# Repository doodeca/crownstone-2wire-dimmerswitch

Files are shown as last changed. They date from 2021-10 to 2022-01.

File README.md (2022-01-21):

# Crownstone 2-Wire Dimmer/switch
A repository to document the design process of the Crownstone 2-wire dimmer/switch prototype.

## Schematics 
| Version | Changes | 
|---|---|
| [V1](https://github.com/doodeca/crownstone-2wire-dimmerswitch/raw/main/hardware/schematics/Schematic_V1.pdf) | First draft |
| [V1.1](https://github.com/doodeca/crownstone-2wire-dimmerswitch/raw/main/hardware/schematics/Schematic_V1.1.pdf) | Replace LDO with a DC/DC converter, replace LNK3302 by LNK302, add opamp for ZCD |
| [V1.2](https://github.com/doodeca/crownstone-2wire-dimmerswitch/raw/main/hardware/schematics/Schematic_V1.2.pdf) | Change value of R5 to 82k |
| [V1.3](https://github.com/doodeca/crownstone-2wire-dimmerswitch/raw/main/hardware/schematics/Schematic_V1.3.pdf) | Add rotary encoder |
| [V1.4](https://github.com/doodeca/crownstone-2wire-dimmerswitch/raw/main/hardware/schematics/Schematic_V1.4.pdf) | Add dimmer circuit, change rotary encoder |

## Simulations
[230V AC - 15V DC buck converter using LinkSwitch, half rectifier](https://github.com/doodeca/crownstone-2wire-dimmerswitch/blob/main/hardware/simulations/Pspice/README.md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)\
[230V AC - 15V DC buck converter using LinkSwitch, full rectifier](https://github.com/doodeca/crownstone-2wire-dimmerswitch/blob/main/hardware/simulations/Pspice/README.md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)\
[3.3V buck converter using LT1934](https://github.com/doodeca/crownstone-2wire-dimmerswitch/blob/main/hardware/simulations/LTspice/README.md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)\
[Zero Cross Detection using an opamp](https://github.com/doodeca/crownstone-2wire-dimmerswitch/blob/main/hardware/simulations/LTspice/README.md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)

## Tests
[15V DC buck converter using LinkSwitch](https://github.com/doodeca/crownstone-2wire-dimmerswitch/blob/main/hardware/tests/README.md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)\
[3.3V buck converter using LT1934](https://github.com/doodeca/crownstone-2wire-dimmerswitch/blob/main/hardware/tests/README.md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)\
[Zero Cross Detection using an opamp](https://github.com/doodeca/crownstone-2wire-dimmerswitch/blob/main/hardware/tests/README.md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)

## Documents
[Report](https://docs.google.com/viewer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)

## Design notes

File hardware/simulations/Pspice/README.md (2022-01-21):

# LNK302 buck converter half rectifier

LinkSwitch-TN series DC/DC converter ICs combine a on/off controller and an integrated switch. LNK302 is used in a buck topology with direct feedback [datasheet](https://ac-dc.power.com/sites/default/files/product-docs/an37.pdf).
PI Expert's [spreadsheet](https://github.com/doodeca/crownstone-2wire-dimmerswitch/raw/main/hardware/simulations/Pspice/LinkSwitch-TN_buck_PIExpert%20.pdf) tool is used to calculate the external component values. 

## Simulation specific components description 

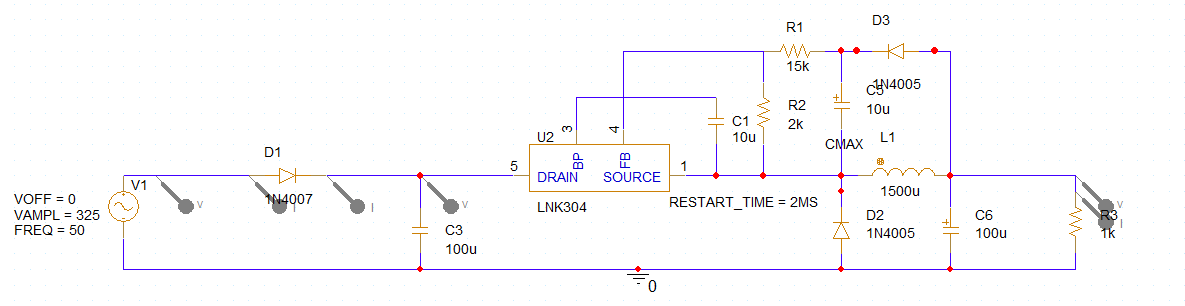
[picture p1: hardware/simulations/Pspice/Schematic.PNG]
Schematic


V1 simulates a 230Vrms source at 50 hertz, R3 simulates the load.

## Simulation results

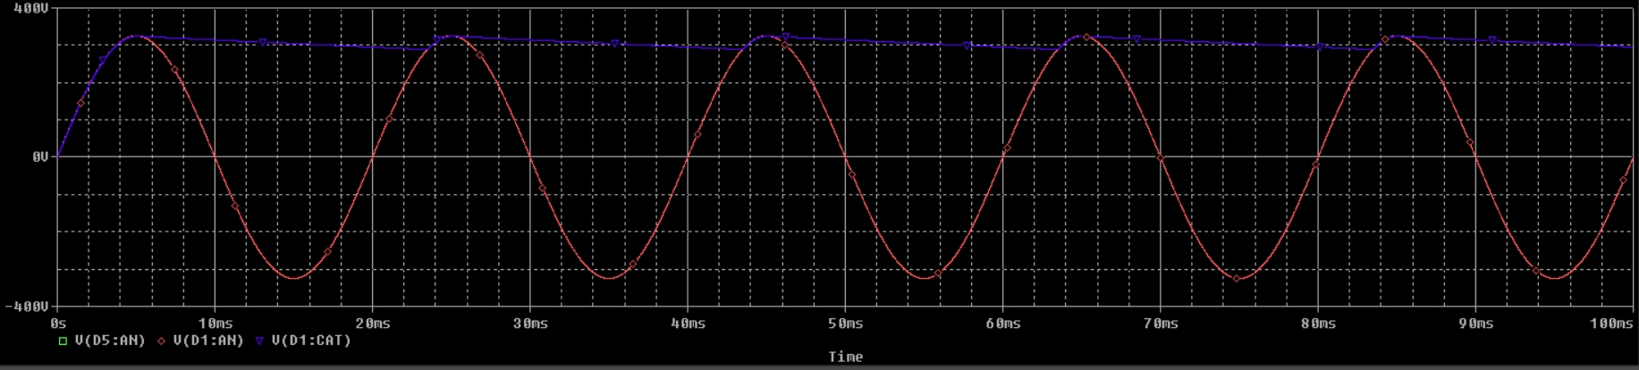
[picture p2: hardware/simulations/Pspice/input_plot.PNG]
Plot_in


This plot shows the input signal (red) and the rectified input (blue).

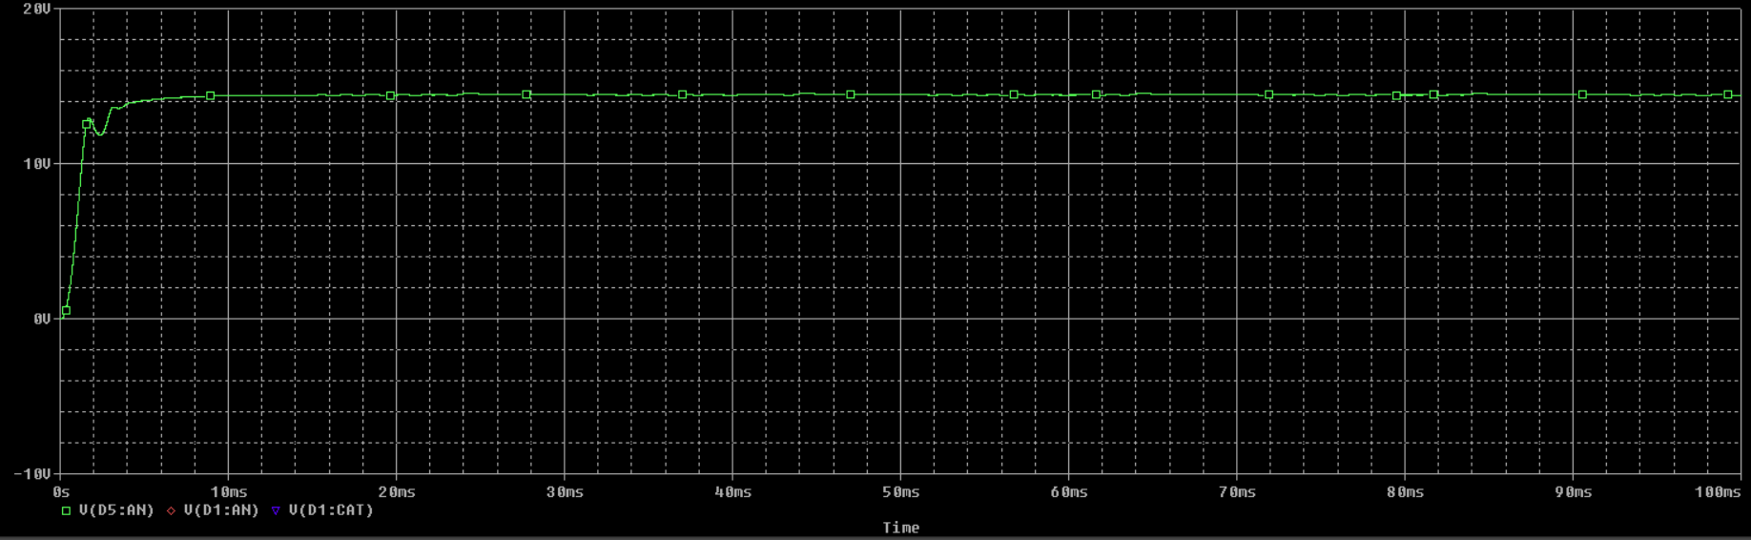
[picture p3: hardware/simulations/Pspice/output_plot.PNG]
Plot_out


In this plot the output voltage is shown.

# LNK302 buck converter full rectifier

## Simulation specific components description 

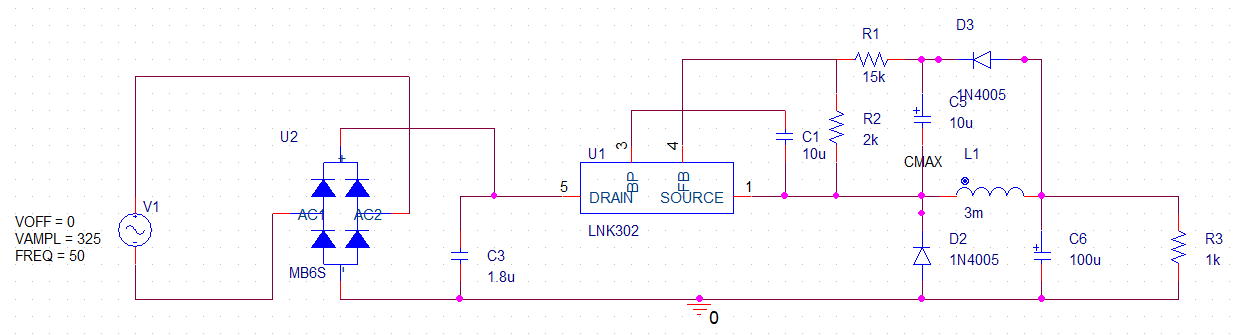
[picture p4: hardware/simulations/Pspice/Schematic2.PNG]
Schematic


V1 simulates a 230Vrms source at 50 hertz, R3 simulates the load.

## Simulation results

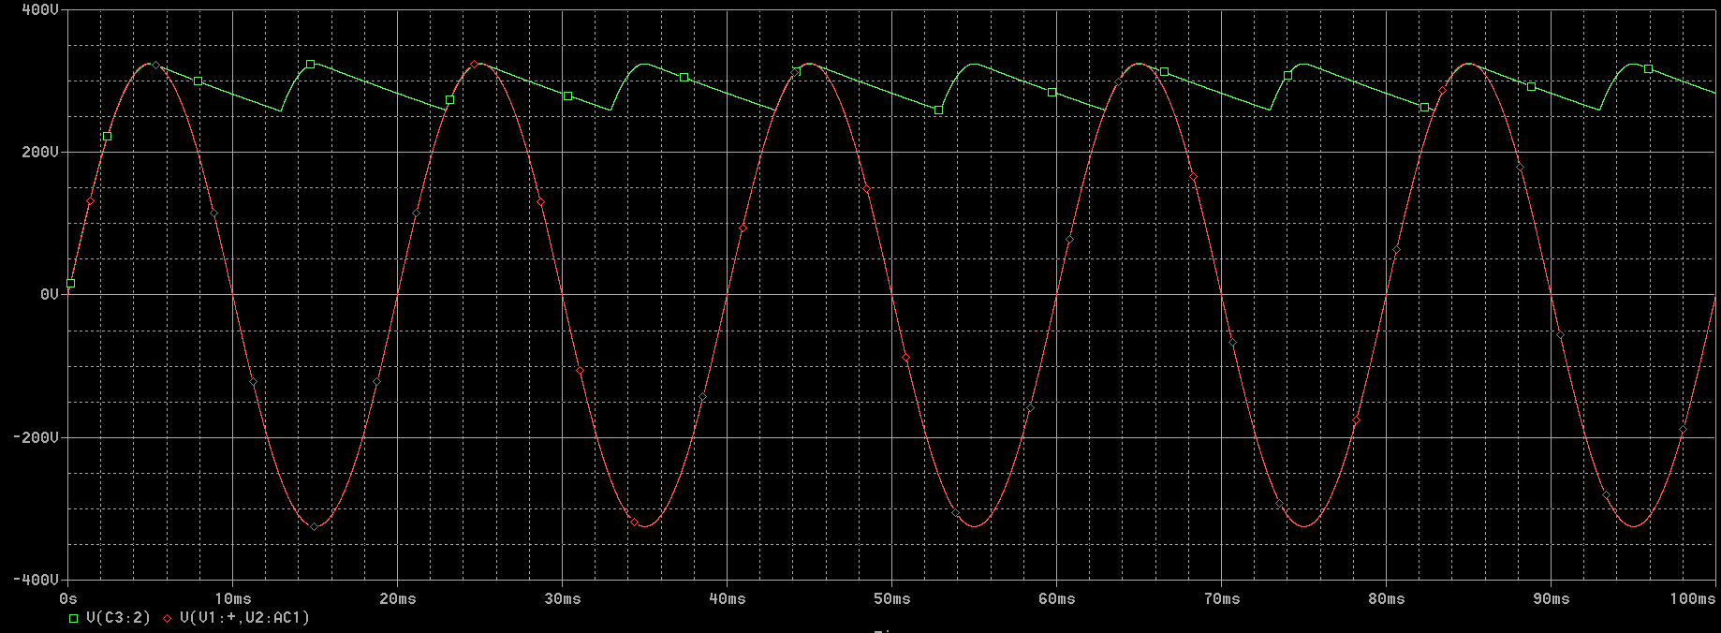
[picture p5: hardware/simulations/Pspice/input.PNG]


This plot shows the input signal (red) and the full rectified input (green).

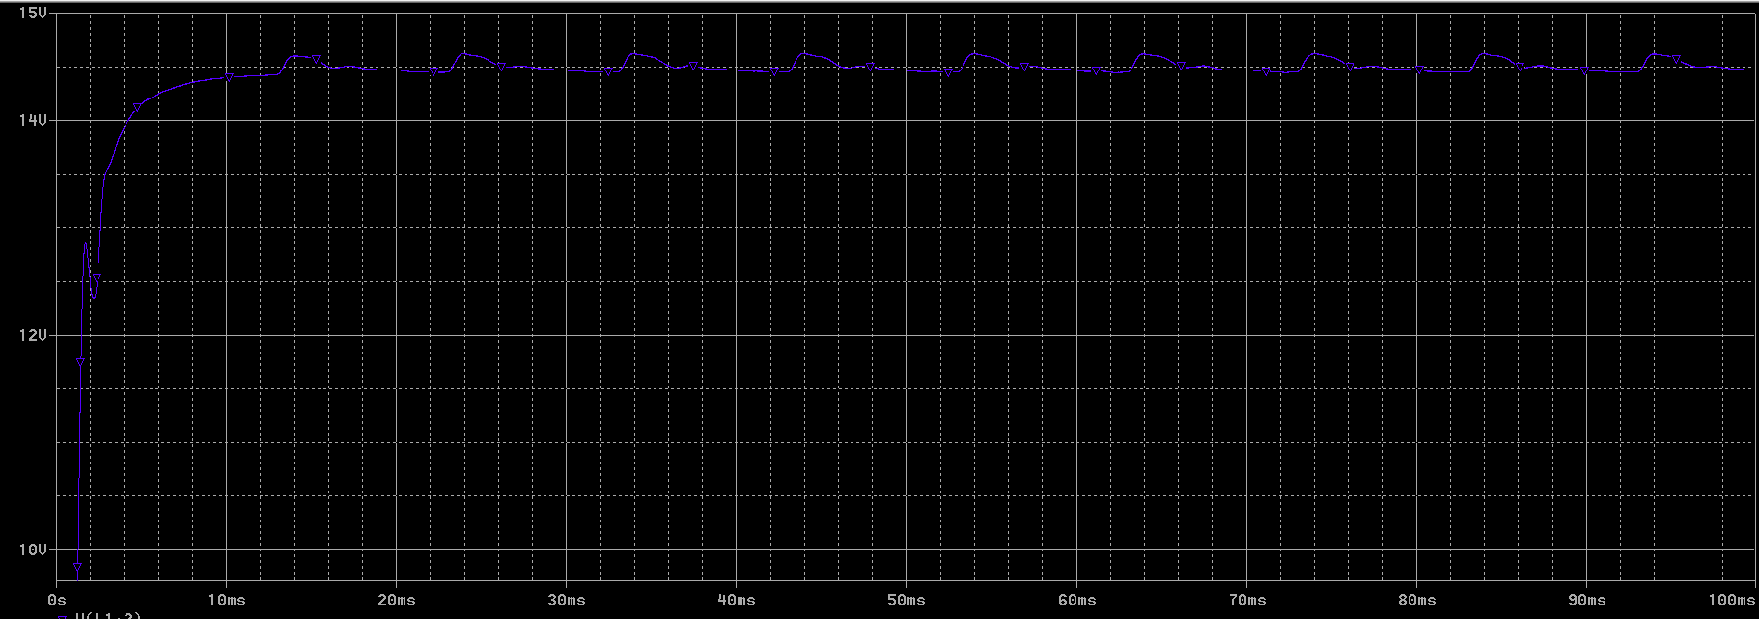
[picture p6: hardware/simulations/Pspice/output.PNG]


In this plot the output voltage is shown.

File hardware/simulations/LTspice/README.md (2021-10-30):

# LT1934-1 buck converter

LT1934-1 is a step-down DC/DC converter IC with an integrated switch, able to supply up to 60mA of output current. [datasheet](https://www.analog.com/media/en/technical-documentation/data-sheets/1934fe.pdf).

## Simulation specific components description 

The purpose of R4 and R5 is to be able to measure the current from the source and the current going into the switching regulator.\
V1 simulates a 15V DC source with a 0.15V sine ripple at 62kHz. B1 simulates a 15V DC source with noise +-0.5V.\
R3 simulates the load.

## Simulation results

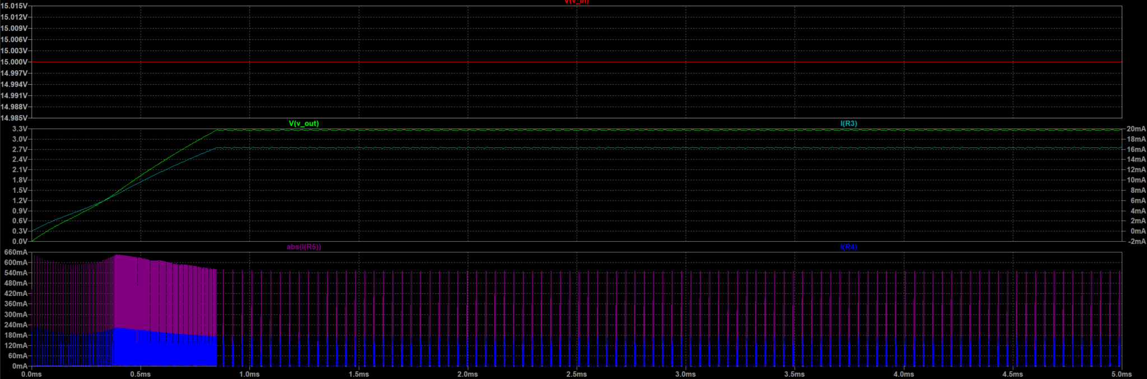
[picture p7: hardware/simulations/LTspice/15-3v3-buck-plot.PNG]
Plot


The top plot shows the input signal (V_in).\
The second plot shows output voltage V_out (green) and the current through the load resistor R3 (blue).\
The last plot shows input current of the converter IC (magenta) and the current draw from from the source (blue).

## Efficiency

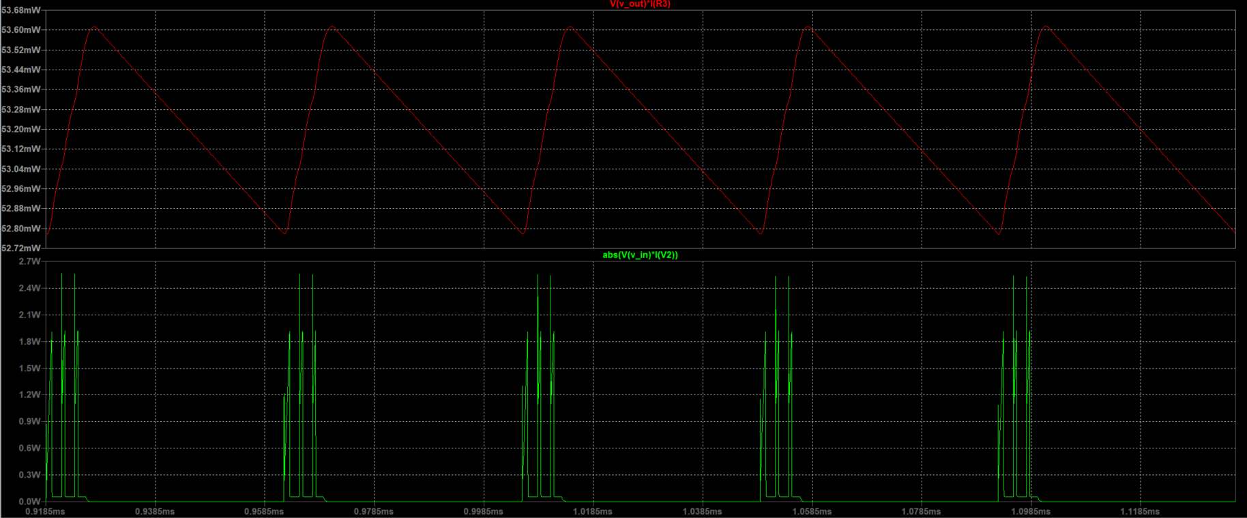
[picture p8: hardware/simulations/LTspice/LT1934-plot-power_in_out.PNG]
Plot


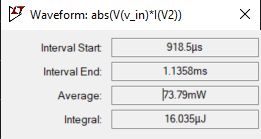
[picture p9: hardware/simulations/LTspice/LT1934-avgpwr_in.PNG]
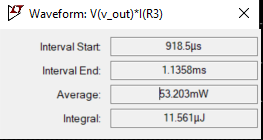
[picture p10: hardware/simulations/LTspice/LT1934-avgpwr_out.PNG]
 

The efficiency is about 53.2mW/73.8mW = 72%

# Zero Cross Detection

This schematic simulates an opamp used for detecting a zero crossing in an AC signal. The opamp used is MCP6L01, a basic rail-to-rail opamp [datasheet](https://ww1.microchip.com/downloads/en/DeviceDoc/MCP6L01-1R-1U-2-4-1-MHz-85-uA-Op-Amps-DS20002140D.pdf). Since there's no spice model available for this opamp, the values from the datasheet were entered in the universal opamp model. 

## Simulation specific components description

V1 and V2 simulate 230V RMS voltage sources (325V pk).
B1 adds white noise to V1. 
U1 is an universal opamp (level 2) model, U2 is identical to U1. 
|Parameter|Value|
|---|---|
|Open loop voltage gain|178k (100dB)|
|Gain bandwidth|1MHz|
|Slew Rate|0.6V/us (=600kV/s)|
|Current Limit|20mA|
|rail=0|rail-to-rail opamp|
|V offset|0.001|
|Input Impedance|500Meg|
|Output Impedance|1k|

## Simulation results

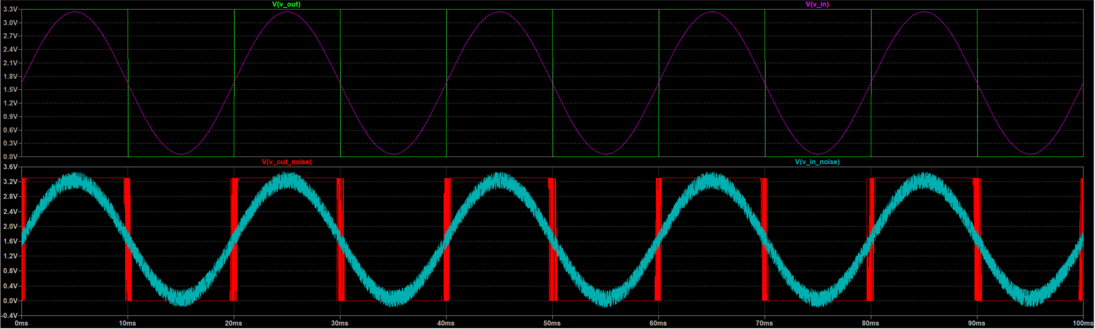
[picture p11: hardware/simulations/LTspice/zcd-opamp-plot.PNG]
Plot


The top plot shows an ideal situation where the input is a perfect sine wave.\
The bottom plot introduces noise in the input (blue), which results in a bouncing of the output signal (red).

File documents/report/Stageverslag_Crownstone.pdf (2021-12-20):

Hogeschool Rotterdam

Electrical Engineering

# Smart Dimmer

Crownstone

# Internship Report

Student
Jaap Sontrop

Company Supervisor
Anne van Rossum

Supervisor
Erwin den Boer

December 20, 2021

## Contents

## List of Figures

1 | Types of dimming [1] | | 6
2 | Schematic representation of the device placement | | 7
3 | Discharge curves at a constant current [8] | | 8
4 | The discharge curve of a NiMH cell [20] | | 8
5 | Current transformer used for electromagnetic harvesting [21] | 10
6 | Circuit diagram of an inductive harvesting device [21] | 10
7 | Schematic representation of the power supply and dimmer/relay | 10
8 | Context diagram | 14
9 | Architecture interconnect diagram | 14
10 | A simplified schematic of a buck converter using a LinkSwitch-TNZ device. [18] . . 17
11 | AC line voltage (blue) and half rectified, flattened signal (red) | 19
12 | A simplified schematic of a buck converter using a LinkSwitch-TN device [17] . . . 19
13 | Output voltage of the LNK302 buck converter | 20
14 | Attenuated AC line (red) and zero-crossing signal (green) | 20
15 | Bouncing output signal caused by noise | 21
16 | Plot of the input current of the buck converter at the device (red) after the
capacitor (blue) | 21
17 | Plot of 5 periods of the output (top) and input (bottom) power | 22
18 | Block diagram of the ACN52832 module Source: [2] | 22
19 | Quadrature output of the rotary encoder [4] | 24
20 | Test results unit test 1.1, 1kΩ load resistor | 26
21 | Test results unit test 1.1, 560Ω load resistor | 26
22 | Test results unit test 1.2 | 27
23 | Test results unit test 1.3, DC output voltage | 30
24 | Test results unit test 1.3, output voltage ripple | 30
25 | Test results unit test 1.5 | 32
26 | Test results unit test 1.5 | 33

## List of Tables

1 | Comparison of dimming techniques | | 7
2 | Power consumed by nRF52832 [14] | | 7
3 | Comparison of a NiMH cell, a supercapacitor and a LiPo battery | | 9
4 | Charge time and average power harvested using CapHarvester in various locations
in the US (110V/60Hz) [9] | | 9
5 | MoSCoW abbreviations | 12
6 | Requirements traceability matrix | 16
7 | Data dictionary | 16
8 | Unit test 1.1, 15V buck converter test | 25
9 | Unit test 1.2, 15V to 3.3V converter test | | 27
10 | Unit test 1.3, low voltage DC test | 29
11 | Unit test 1.4, Power supply AC test | 31
12 | Unit test 1.5, zero-crossing detection | 32
13 | Unit test 1.6, complete power supply test | 33
14 | Unit test 2.1, NAAM | | 34
15 | Unit test 3.1, NAAM | 34
16 | Integration test 1, NAAM | 35

## Summary

Crownstone (http://crownstone.rocks) is an innovative company based in Rotterdam, designer and manufacturer of smart plugs and connectors with a focus on indoor positioning of smartphones and wearables.
To offer a more complete range of products, Crownstone wants to expand its smart home product line with a smart wall switch and wall dimmer. In developing this product, Crownstone is collaborating with a company that specializes in product development in home automation. While Crownstone will focus on electronics, the collaboration partner will provide 3D models and prototypes for the housing.

It’s essential that the wall dimmer operate without using a neutral wire since the switch boxes in older homes are only equipped with a live and switching wire to the lamp. Besides that, the dimmer should dim both energy-efficient LED lights and conventional lamps. In order to realize a prototype in this assignment, the report will start with a theoretical study of the topic. First, the research will focus on different techniques used for dimming AC signals. Then on methods for supplying the circuit with power, without using a neutral wire.
The report will first focus on options to power the device using stored energy, such as a battery or capacitor. After that on possibilities to harvest energy for powering the device.

## Samenvatting

Crownstone, (http://crownstone.rocks) gevestigd te Rotterdam, is ontwerper en fabrikant van slimme stekkers en connectoren (kroonsteentjes). Waarbij de focus ligt op positiebepaling van smartphones en wearables binnenshuis.
Crownstone wil door het assortiment uit te breiden naar slimme wandschakelaars en wanddimmers een nog completer assortiment aanbieden. Bij het uitwerken van dit product werkt Crownstone samen met een bedrijf dat zich specialiseert in productontwikkeling op het gebied van domotica. Waar Crownstone zich zal richten op de elektronica, levert de samenwerkingspartner 3D-modellen en prototypes voor de behuizing.

Het is van belang dat de wanddimmer moet kunnen werken zonder neutrale draad, omdat er in oudere woningen vaak enkel een fase en schakeldraad op de plaats van de inbouwdoos te vinden is. Verder moeten er zowel energiezuinige ledlampen als conventionele lampen gedimt kunnen worden.

Om in deze opdracht een prototype te realiseren, zal er in het verslag eerst een theoretische verdieping worden gedaan. Allereerst zal dit onderzoek zich richten op verschillende technieken gebruikt om te dimmen bij een wisselspanningsbron. Daarna op het voeden van het circuit zonder gebruik te maken van een nuldraad. Hierin zal eerst de focus liggen op het opslaan van energie en daarna op het verkrijgen (’oogsten’) van energie uit de omgeving van het apparaat.

## 1 Introduction

This chapter describes the assignment of the internship and gives a brief description of Crownstone.

### 1.1 About Crownstone

Crownstone, (http://crownstone.rocks) an innovative company based in Rotterdam, builders of smart plugs and connectors (Dutch: kroonsteentjes). Crownstone develops small form factor modules which can be put behind a power outlet. This module is a 16A switch, LED dimmer, power meter, soft-fuse, standby-killer and presence sensor in one device. The unique selling point is the indoor localisation of smartphones and wearables, which makes it possible to automatically turn on and off or dim lights based on the user’s presence.

### 1.2 Problem definition

Crownstone would like to expand its product line around smart home products. The available Crownstone modules are made to be placed behind a wall outlet or light switch. Crownstone can offer an even more complete range of products by developing smart wall switches and smart wall dimmers.
In this product, it’s essential that no neutral line is necessary for operation since the switch boxes in older homes are only equipped with a live and switching wire.

### 1.3 Assignment and objective

The final goal of this internship is to realise a prototype of a smart wall switch and dimmer. Initially, the prototype will make use of an nRF52832 (https://www.nordicsemi.com/products/nrf52832) microcontroller. This is a Bluetooth 5.2 System-on-Chip (SoC) with support for Bluetooth Low Energy (BLE) and Bluetooth mesh.
In a later prototype an nRF5340 (https://www.nordicsemi.com/products/nrf5340) or nRF9160 (https://www.nordicsemi.com/products/nrf9160) microcontroller will be used. Where nRF5340 has the same features as the microcontroller used in the first prototype, but has a dual-core and supports Zigbee and Thread. The nRF9160 is a low power System-in-Package (SiP) with an integrated LTE-M/NB-IoT modem and GPS.

## 2 Research and analysis

As part of this internship, short research is conducted to orient various possible solutions for the design. First, the research will focus on two techniques used for dimming. After that, ways to power the circuit will be discussed.

### 2.1 Goal

The aim of this research is to find a suitable solution for realising a dimmer circuit that can operate in a 2-wire configuration. This means no neutral wire is needed for using the dimmer.

Main question and sub-questions

How can a dimmer/switch be powered without the use of a neutral wire?

What techniques are used for dimming AC signals?
Is stored energy suitable for powering a dimmer/switch?
Can the dimmer powered of energy harvested from the environment?

### 2.2 Dimming

The most conventional method of AC mains dimming is phase-cut dimming. In this technique, a part of the AC wave is cut off (figure 1).
In phase-cut dimming, there are two possible implementations leading-edge or forward phase, which cuts off in the first part of the half-cycle (figure 1a). Since the point of turning on varies in a leading-edge dimmer, the AC signal will get a steep rising edge [12]. Dimming capacitive loads, such as LED drivers, causes large current spikes.
Trailing edge or reverse phase dimming cuts off in the second part of the half-cycle (figure 1b). The load always turns on at the zero-crossing of the AC line cycle. This allows the current to rise with the mains voltage naturally. This type of dimming is more effective on capacitive loads since there is no fast rise in the AC signal.

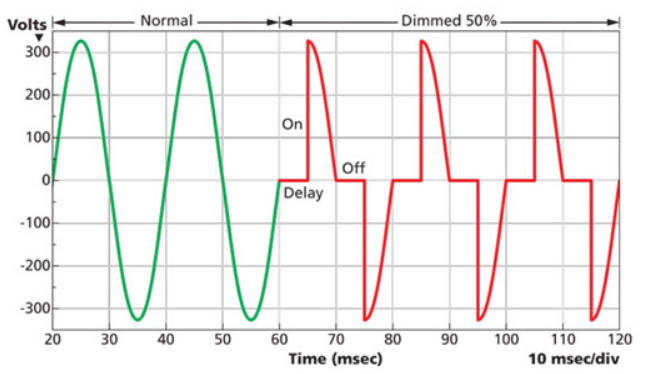
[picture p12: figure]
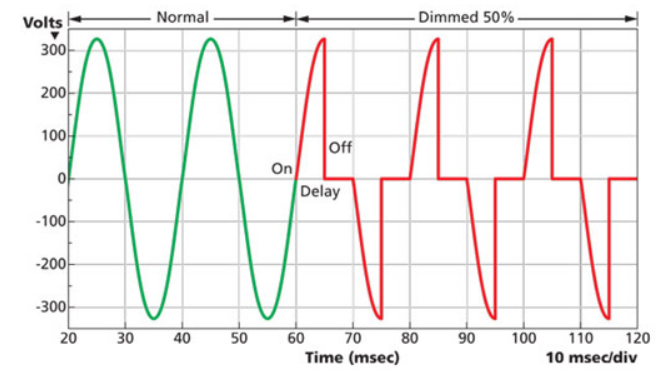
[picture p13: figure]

(a) Leading edge | (b) Trailing edge

Figure 1: Types of dimming [1]

Type | Description | Possible components
Leading edge | Switching on of the AC power is de-
| layed, the first part of the period is cut
| off. | SCR: triac, thyristor
| | Transistor: IGBT,
| | MOSFET
| Circuit realatively easy to realise. Most
| suitable for inductive loads: transform-
| ers and motors
Trailing edge | Switching off the AC power early, the
| second part of the period is cut off | Transistor: IGBT, MOSFET
| Most suitable for capacitive or resis-
| tive loads: LED lighting, TL en con-
| ventional bulbs

Table 1: Comparison of dimming techniques

### 2.3 Powering the device

As section 3.1 shows, the output switching part of the dimmer will consist of two main components: a relay and a dimmer. When the load is turned off, a voltage will drop over the relay and dimmer. This voltage drop can be used to power the microcontroller. Figure 2 shows how the dimmer and power supply would be inserted in the circuit, where the wire to the lamp acts as the neutral wire to the device.

Figure 2: Schematic representation of the device placement

However, when the load is switched on, the voltage drop across the relay will disappear, and there won’t be any power for the microcontroller or for switching the relay. The following sections will discuss the possibilities for powering the microcontroller for when the load is switched on.

### 2.3.1 Storing energy

One possible solution would be using (rechargeable) batteries or a supercapacitor to power the device when the load is switched on. The battery needs to be able to power the microcontroller for a given amount of time and switch back the relay to turn off the load.
According to the datasheet for the ADW1212 [15], the relay used in the Crownstone Built-in devices, the voltage and current needed to switch are 12V and 33,3mA. For switching, the coil needs to be powered for 15 milliseconds. This results in a total charge of approximately 500µC (equation (1)).
E = I × U × t, E = Q × U, | Qset/reset = 33.3mA × 15ms ≈ 500µC | (1)
Radio transmitting | 8.9mA
Radio receiving | 6.7mA
Radio standby | 3.4mA
Standby | 1.9mA
Idle | 2.0µA

Table 2: Power consumed by nRF52832 [14]

The current usage of the nRF52832 SoC strongly depends on the usage of the radio (table 2), according to Nordic’s power profiler [13]. If the SoC has BLE events in an interval of 25ms with every event using about 17µC, the total charge needed for one hour of operation would be 17µC × 40 × 3600 = 2.45C.

Supercapacitor

Using an Eaton TV-series supercapacitor [7] with a capacitance of 6F at 3V holds a charge of 18C. This could, in theory, power the microcontroller for 18C/2.45C ≈ 7 hours.

However, in practice, this doesn’t hold up since there are losses. First of all the supercapacitor used in the example above has a nominal leakage current of 13µA, this means the capacitor will slowly discharge itself in 7.5mW h
3.0V×13µA ≈ 192 hours.

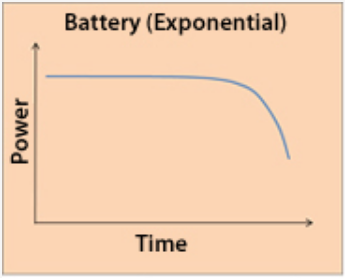
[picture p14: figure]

(a) Battery | (b) Supercapacitor

Figure 3: Discharge curves at a constant current [8]

Secondly, the voltage across the capacitor decreases linearly (figure 3b) unlike a battery, where the voltage remains almost the same for most of the time (figure 3a). As a result of the voltage decreasing, not all the energy stored in the capacitor can be used.
According to Nordic’s nRF52832 product specifications [14], the microcontroller can operate on a supply voltage range of 1.7V-3.6V. With the voltage of the supercapacitor [7] linearly decreasing, only about 1.7V
3.0V × 100% ≈ 56% of the energy stored in the capacitor can be used by the microcontroller.

Rechargeable battery

A wide variety of rechargeable batteries are available, the most common types being Nickel-Metal hydride (NiMH) and Lithium-polymer (LiPo).

Figure 4: The discharge curve of a NiMH cell [20]

Both NiMH and LiPo batteries have similar discharge curves (figure 4), where they’re usable to about 90% of their capacity. After this point, the voltage of the cells drops quickly. The main disadvantage of these cells is that they require specialized charging circuits.

Comparison

As shown in table 3, the charge times and capacity of the three solutions are quite different. The best fit for this application would be a LiPo cell, since this type of battery can power the circuit relatively long and is able to charge in a shorter time.

| NiMH [20] | Supercap [7] | LiPo [19]
Self discharge | up to 3%/month | 13µA leakage | 5-10%/month
Max. Charge current | 8mA | 7.4A | 75mA
Charge time | min. 10 hours | min. 2 seconds | min. 1 hour
Lifespan | 700-1000 cycles | about 500.000 cycles | 500-1000 cycles
Operating temperature | -20 - 35 °C | -40 - 60 °C | 0 - 35 °C
Capacity | 288mWh | 7.5mWh | 550mWh
Volume | 11 x 22mm | 16 x 24mm | 24 x 10 x 5mm

Table 3: Comparison of a NiMH cell, a supercapacitor and a LiPo battery

### 2.3.2 Energy harvesting

An alternative way to power the microcontroller would be to harvest power from the dimmer’s environment. A few different techniques for harvesting power will be described in the following sections.

Capacitive energy harvesting

The CapHarvester, as described in the article, [9] is a device that clamps onto a low voltage domestic power cable and harvests power without current flow.
The system consists of four main components: capacitive electrodes, a diode bridge rectifier, a storage capacitor and a MOSFET for high side switching.
The charging time and thus the average power of the system strongly depends on the placement of the CapHarvester (table 4), where the coupling to earth ground is most of interest.
Besides the placement, the average power is also influenced by the capacitive coupling of cable types (length, different gauges and outer shielding).
Location | Surface | Charge Time (s) | Average Power (µW)
Ground floor of cement office building | Tile floor | 277 | 0.95
Fifth floor of cement office building | Carpet | 731 | 0.36
Second floor of wooden house | Carpet | 1308 | 0.20
Outdoors | Concrete | 242 | 1.09
Wooden Stud | Wood | 780 | 0.34
Wooden Attic | Wood | 2356 | 0.11
Wooden floor | Wood | 2500 | 0.11
Residential basement | Carpet | 653 | 0.40
Table in residential basement | Wood | 617 | 0.43
Residential garage | Epoxy coating | 267 | 0.99
Fifth floor of a cement lab rotary building | Epoxy coating | 467 | 0.57

Table 4: Charge time and average power harvested using CapHarvester in various locations in the US (110V/60Hz) [9]

The main problem when using the CapHarvester is that when it’s suspended in free air or placed on drywall, the device won’t work due to the poor coupling to earth ground. This makes this technique less suitable for smart switches, which are commonly placed in walls.

Inductive energy harvesting

This type of energy harvesting relies on the current flow through a conductor, which produces a magnetic field around the conductor, the same technique used in a transformer.
The electromagnetic harvesting device described in the article [21] uses a current transformer with a winding ratio of 1:1200 (figure 5, figure 6), where the single turn is the live wire carrying the current to the load.

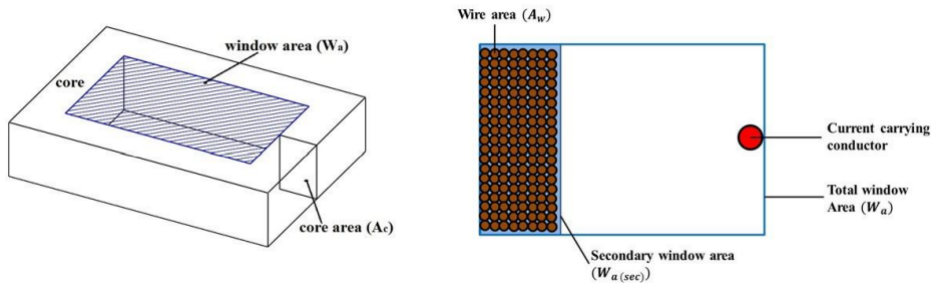
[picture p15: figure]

Figure 5: Current transformer used for electromagnetic harvesting [21]

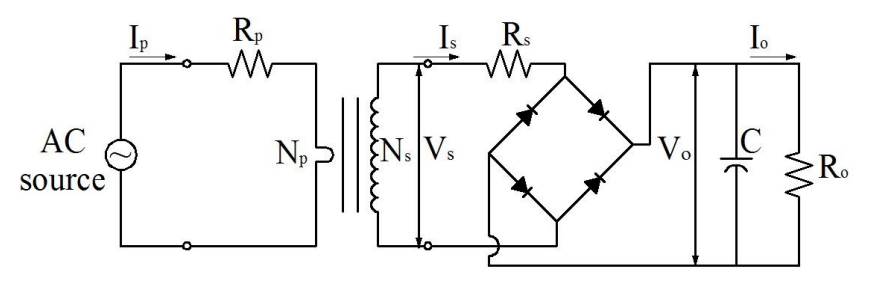
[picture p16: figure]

Figure 6: Circuit diagram of an inductive harvesting device [21]

Harvesting power from the magnetic field caused by the current flow through the conductor would need a For harvesting power from the magnetic field around the conductors inside walls, a significant current needs to flow thought the conductor (> 1A). This requires a heavy load with a minimum power draw of about 230 Watt. In most indoor lighting applications the power doesn’t exceed 100 Watt, this results in not enough energy in the magnetic field.

### 2.3.3 Creating a voltage drop

A third possible solution would be to interrupt the power to the load for short periods of time. Doing this creates a voltage drop which can be used to power the microcontroller.

Figure 7: Schematic representation of the power supply and dimmer/relay

A possible implementation for interrupting the power would be adding a MOSFET [10] or IGBT [12] in series with the AC line as schematically shown in figure 7.
In this setup, when the MOSFET is on, the current will flow through the dimmer and power the load. When the MOSFET is turned off, a voltage drop will be available for the power supply.

### 2.4 Conclusion

Storing energy, as discussed in section 2.3.1 isn’t a realistic solution for powering the dimmer. Mainly because of the limited time that the light can stay on, but also because of the high cost (supercapacitor) or the charge times (NiMH/LiPo) and the limited life span (NiMH/LiPo).

Harvesting energy from the environment is a technique that is more suited to low power applications. For instance remote switches, which only use the SoCs radio when a switch event occurs. Unlike dimmers, which constantly need sufficient power. Another disadvantage of energy harvesting is it being voluminous.

The most effective solution for powering the dimmer and microcontroller is creating a voltage drop, as described in section 2.3.3. This technique allows for two-wire operation of the dimmer and doesn’t limit the time that the lamp can stay on.

## 3 Definition phase

### 3.1 Program of requirements

This section will discuss the system’s requirements. All requirements are categorized using the MoSCoW method (table 5).

Abbreviation | Meaning
MH | Must Have | This requirement needs to be developed to ensure proper
| | functioning of the product.
SH | Should Have | Not necessary, but meeting this requirement is desirable.
CH | Could Have | Not necessary, only when there is time.
WH | Won’t Have | Not needed.

Table 5: MoSCoW abbreviations

### 3.1.1 Power supply

REQ-1.1[MH] | The system shall operate on a voltage between 207V and 253V RMS.
REQ-1.2[MH] | The system shall be able to operate without the need of a neutral wire (2-wire).
REQ-1.3[SH] | The system shall be able to operate with the use of a neutral wire (3-wire).
REQ-1.4[MH] | Zero-crossings of the AC line shall be detected.

### 3.1.2 Dimmer and switch

REQ-2.1[MH] | The system shall have a leading-edge dimming mode.
REQ-2.2[MH] | The system shall have a trailing-edge dimming mode.
REQ-2.3[MH] | The system shall be able to continuously dim loads up to 100 W
REQ-2.4[MH] | The system shall be able to dim all types of dimmable bulbs.
REQ-2.5[MH] | The system will be controlled via Bluetooth.
REQ-2.6[SH] | The system will be controlled via a rotary knob.
REQ-3.1[CH] | The product will have a relay to switch high power loads.
REQ-3.2[CH] | The relay shall be switched on a zero-crossing of the AC power.

### 3.1.3 Microcontroller

REQ-4.1[MH] | The system shall use a certified nRF52832 module.
REQ-4.2[MH] | The SoC module shall have an integrated antenna.
REQ-4.3[MH] | The SoC shall run Crownstone’s Bluenet firmware. (https://www.github.com/crownstone/bluenet)
REQ-4.4[MH] | The system shall have an UART connection for debugging.
REQ-4.5[MH] | The system shall be programmed via the SWD connection.

### 3.1.4 Safety requirements

REQ-5.1[MH] | The product will shut down when the temperature gets too high.
REQ-5.2[SH] | The product shall have overcurrent protection.
REQ-5.3[SH] | The product shall have input surge protection.
REQ-5.4[SH] | The product will be protected against wrong connections.
REQ-5.5[MH] | The product will discharge after disconnecting AC power.

### 3.1.5 Non-Functional requirements

REQNF-1[MH] The connectors shall be suitable for solid core 2.5mm²
| cables.
REQNF-2[MH] The connectors shall be suitable for solid core 1.5mm²
| cables.
REQNF-3[MH] The PCB shall fit within the 3D model of the housing. REQNF-4[SH] The bottom side of the PCB shall have a debug connector.

REQNF-5[MH] The connectors will be VDE certified. REQNF-6[MH] The product will not produce any audible noise.

## 4 Architecture phase

This chapter will describe the structure of the system. The architecture will describe all subsystems and their connections.

### 4.1 Context diagram

The context diagram in figure 8 shows how the external sources interact with the system.
The diagram consists of three terminators and the general function of the system. The user can provide a dimmer value to the system and vice versa. The system connects to the mains power via the line wire. The dimmer output wire doubles as a neutral wire to the system since it connects to the neutral wire via the lamp.

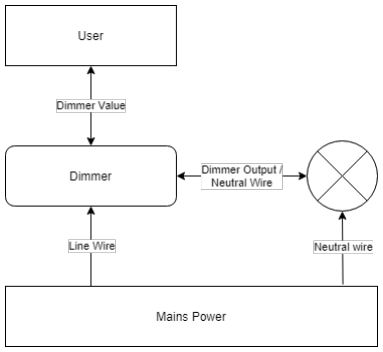
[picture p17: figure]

Figure 8: Context diagram

### 4.2 Architecture Interconnect Diagram

The architecture interconnect diagram (figure 9) gives a more detailed overview of the system. This diagram shows the connections between the three subsystems (Power supply, Microcontroller and Dimmer) and their external connections as shown in figure 8.

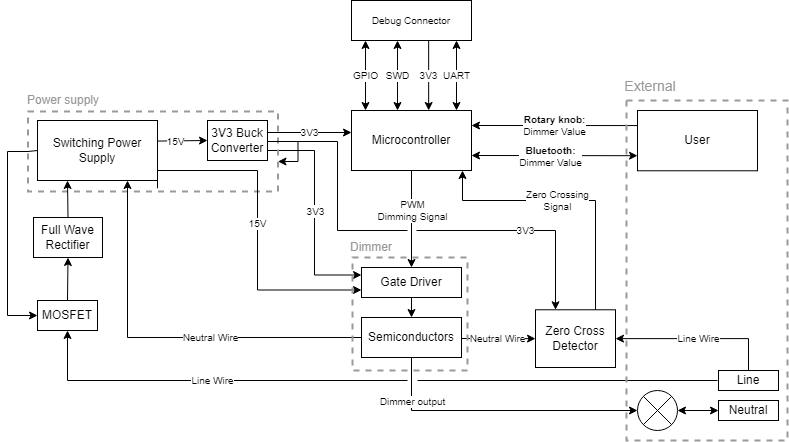
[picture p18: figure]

Figure 9: Architecture interconnect diagram

### 4.3 Subsystems

The system consists of three subsystems, the following sections will briefly describe these subsystems, and the data flows between them.

### 4.3.1 Power supply

The power supply contains four parts: a half-wave rectifier, DC to DC power converters and zero-crossing detection.
This subsystem provides power at the right voltage for the gate driver and microcontroller. The zero-crossing system will supply a square wave signal to the microcontroller.

### 4.3.2 Microcontroller

The microcontroller is part of the SoC, which handles Bluetooth communication and ensures that all subsystems are connected. It receives the zero-crossing detection signal from the power supply, detects the use of the rotary knob and sends a PWM signal to the dimmer system.
External connections to the microcontroller for debug purposes are UART, Serial Wire Debug, four GPIO pins and the ability to power the microcontroller from an external power source.

### 4.3.3 Dimmer

The dimmer generates the phase-cut output signal from a PWM signal derived from the microcontroller.
This subsystem consists of two semiconductors for phase cutting the output signal and a gate driver to drive the semiconductors.

### 4.4 Traceability of requirements

The Requirements traceability matrix shows which subsystem is responsible for a requirement.

Power supply | Microcontroller | Dimmer
REQ-1.1 | ✓ | | ✓
REQ-1.2 | ✓ | | ✓
REQ-1.3 | ✓
REQ-1.4 | ✓ | ✓
REQ-2.1 | | ✓ | ✓
REQ-2.2 | | ✓ | ✓
REQ-2.3 | ✓ | | ✓
REQ-2.4 | | | ✓
REQ-2.5 | | ✓
REQ-2.6 | | ✓
REQ-3.1 | 1.
REQ-3.2 | | ✓
REQ-4.1 | | ✓
REQ-4.2 | | ✓
REQ-4.3 | | ✓
REQ-4.4 | | ✓
REQ-4.5 | | ✓
REQ-5.1 | ✓ | | ✓
REQ-5.2 | ✓
REQ-5.3 | ✓
REQ-5.4 | ✓ | | ✓
REQ-5.5 | ✓
NFREQ-1 | ✓
NFREQ-2 | ✓

NFREQ-3 | ✓ | ✓ | ✓
NFREQ-4 | ✓
NFREQ-5 | ✓ | | ✓
NFREQ-6 | ✓ | ✓ | ✓

Table 6: Requirements traceability matrix

### 4.5 Data dictionary

The data dictionary shows the connections as displayed in the architecture interconnect diagram (figure 9), table 7 shows a description of the flow, the unit and range.

Data flow | Description | Unit | Range
Power supply:
Zero-crossing signal | High-low transitioning signal | Volts | 0 - 3.3
Power input | Mains AC power input | Volts (RMS) | 207 - 253
Microcontroller:
Dimmer value: knob | 0 - 100%
Dimmer value: Bluetooth | 0 - 100%
Dimmer:
PWM dimming signal | Signal from the microcontroller to the dimmer | Duty cycle | 0 - 100%
Dimmer output | Phase cut AC power from the dimmer to the light | Duty cycle | 0 - 100%

Debug connector:
UART | Receive, Transmit | Baud | 115200
SWD | Clock, I/O | - | -
GPIO | General purpose I/O for debugging | - | -
3V3, GND | External MCU 3V3 power input | Volts | 3.0 - 3.6

Table 7: Data dictionary

## 5 Design phase

To realise the architecture described in section 4 This chapter describes all hardware in the subsystems in detail. The schematics can be found in appendix A and appendix B.

### 5.1 Power supply

The power supply will consist of three stages. The first stage rectifies the AC line voltage, the second stage converts the rectified voltage to 15V DC for driving the IGBTs and creates the zero-crossing signal. The last stage converts the 15V DC to 3.3V DC to supply the SoC.

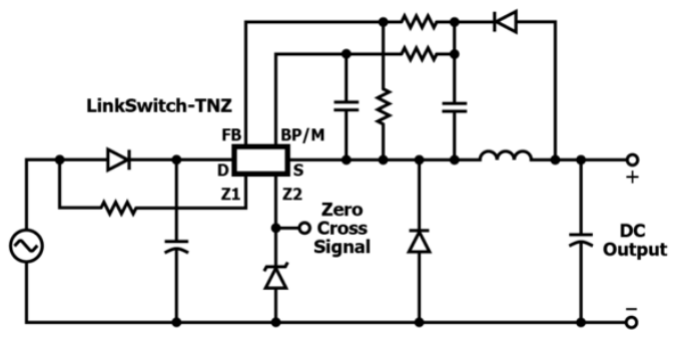
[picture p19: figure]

Figure 10: A simplified schematic of a buck converter using a LinkSwitch-TNZ device. [18]

### 5.1.1 Input stage

As shown in the schematic in A, the input power is half-wave rectified by diode D2. C1 is a bulk capacitor that flattens the rectified AC voltage.
Varistor VAR1 provides input surge protection.

### 5.1.2 Input DC/DC converter using LNK3302

For converting the AC line voltage to 15 VDC, an off-line switching regulator is used. In this category, there are many components to choose from. The LinkSwitch-TNZ series of off-line switchers is selected because it combines a high-voltage power MOSFET switch, a power supply controller, and a zero-crossing detector in a single device. Which is ideal for this application since it reduces the number of external components needed for the power supply and zero-crossing circuit.
Based on the typical output current for a non-isolated buck configuration, given in the datasheet [18], LNK33x2D is chosen. This device can supply up to 80mA of current in continuous conduction mode. Two versions of this IC are available, LNK3302D and LNK3312D, the difference being the ability to discharge an X-capacitor. Since this will not be necessary, LNK3302D is chosen.

The LinkSwitch device is configured as a high-side buck converter (figure 10). For calculating the values of external passive components needed for operation of the LinkSwitch IC, PI Expert’s spreadsheet is used (appendix C). This is a hardware design tool from Power Integrations, manufacturer of the LinkSwitch-TNZ ICs.

The most important input parameters for the design tool are:

- Input voltage of 230V RMS ±10% at a frequency of 50 Hz
- Output voltage of 15V DC
- Maximum output current of 60mA
- Forward voltage drop of the freewheeling diode (D7)

The most useful output parameters of the design tool are:

- Input capacitor value (C1)
- Inductor value (L1)
- Feedback resistor value (R2)

- Feedback capacitor value (C3)
- Bypass pin resistor value (R3)
- Bias resistor value (R1)

### 5.1.3 Zero-crossing circuit

The microcontroller should switch on the semiconductors when the AC signal crosses zero. For this, the microcontroller needs a zero-crossing signal. LNK3302D can provide this zero-crossing signal, which toggles each time the AC line crosses zero volts.
For the zero-crossing signal to be read by the microcontroller, it needs to be within the operating voltage range of the chip. N-MOSFET Q1 converts the zero-crossing signal to the correct logic level for the microcontroller.
C4 and R6 form a low pass filter for the zero-crossing output of the LinkSwitch IC. The signal toggles every half AC line cycle, so the frequency should be 50 Hz, the same as that of the AC line. R7 is the pulldown resistor on the gate of Q1. D3 and D4 form the sensing circuit with R4 in series with zenerdiode D6.

### 5.1.4 LDO

To supply a steady 3.3V to the SoC module, an Low Dropout Regulator (LDO) is added. According to the datasheet of the module [2], the maximum current consumption of the module is 9.6mA. For this purpose, the LP2985-N with a fixed output voltage of 3.3V is chosen, mainly because of the relatively high DC input voltage of 16,V [22] and it needs a minimal amount of external components.
This design will not use the shutdown function of the regulator, the ON/OFF will be tied to VIN to always keep the regulator in normal operation mode.
Capacitor C7 is a noise bypass capacitor, allowing a low-noise output of the LDO [22].
The power loss of the device is given by equation (2), to calculate the efficiency η of the LDO

PIN −PLOSS

PIN

is used.

PLOSS = (VIN − 3.3V) × IOUT + VIN × IQ ≈ (15V − 3.3V) × 15mA ≈ 176mW | (2)

When the LDO is in operation, IOUT ≫ IQ. Therefore IQ is negligible, which allows to further reduce the efficiency to equation (3).

η =

VOUT

VIN

=

3.3V
15V
= 22% | (3)

### 5.2 Power supply (2nd iteration)

The first version of the power supply as described in section 5.1, had some limitations. The most significant limiting factors of the circuit are the availability of certain components and the high power dissipation of the LDO.
This second version of the power supply will have the same output specifications but will focus more on the availability of the used components. The schematics for this version can be found in appendix B.
The power supply is made up of four subsystems, the input stage which rectifies the AC line voltage, two switching voltage regulators and a zero-crossing circuit.

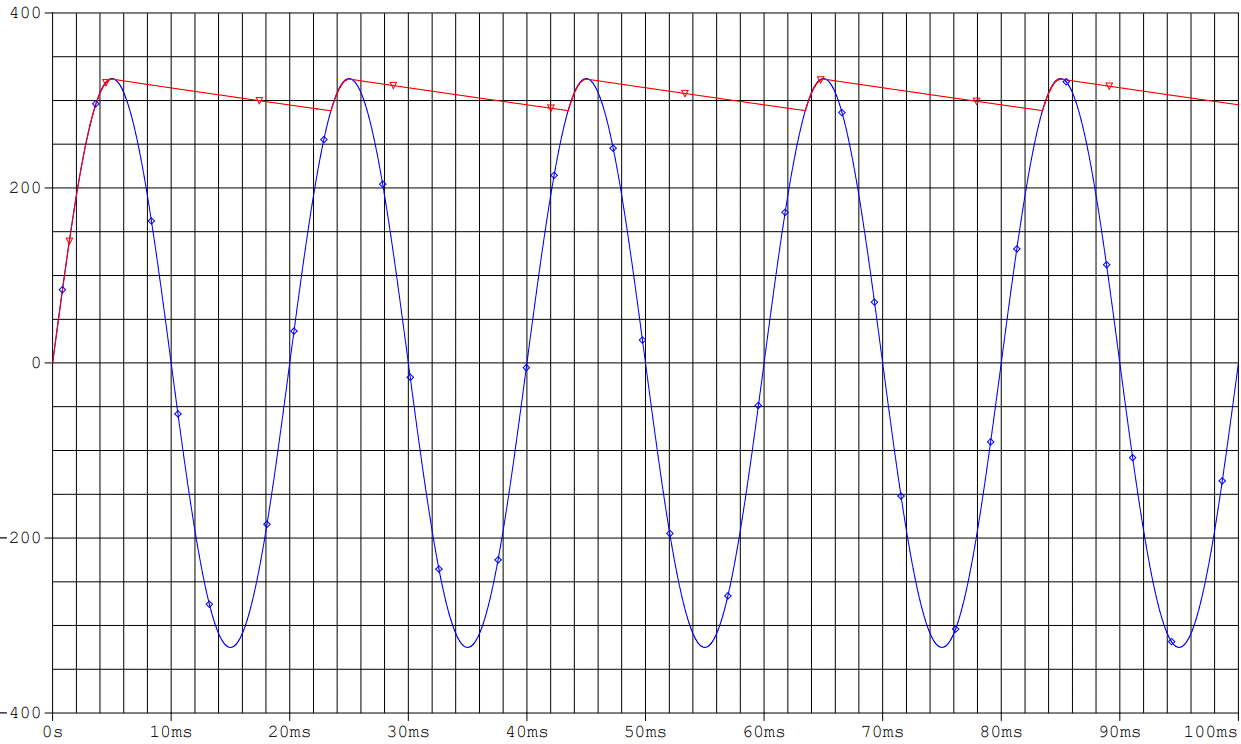
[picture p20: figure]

Figure 11: AC line voltage (blue) and half rectified, flattened signal (red)

### 5.2.1 Input stage

As shown in the schematic in B, the input power is half-wave rectified by diode D2. C1 is a bulk capacitor that flattens the rectified AC voltage (figure 11).
Varistor VAR1 provides input surge protection. Fuse F1 is for safety protection against circuit failure.

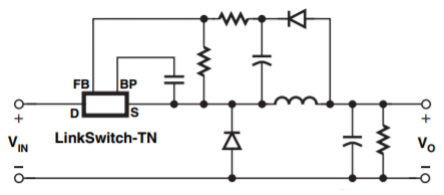
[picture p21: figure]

Figure 12: A simplified schematic of a buck converter using a LinkSwitch-TN device [17]

Voltage drop circuit

As described in subsubsection 2.3.3, a voltage drop will be used to power the circuit. To create this voltage drop, a MOSFET is added in series with the input AC line.
Initially, the MOSFET is off. Creating a voltage drop for the power supply.

2.todo, aanvullen

### 5.2.2 Input DC/DC converter using LNK302

LinkSwitch-TN devices integrate a 700V power MOSFET and a power supply controller, using simple on/off controlling for regulating the output voltage. LinkSwitch-TN devices are available in four types, with different output power capabilities. According to the datasheet [17], LNK302 can deliver up to 63mA of output current, which suits the needs of the circuit.

In this design, LNK302 is configured as a buck converter with direct feedback (figure 12). For calculating the values of the external components needed, PI Expert’s spreadsheet is used. The complete spreadsheet can be found in appendix D.
The most important input parameters for the design tool are:
- Input voltage of 230VRMS ± 10% at a frequency of 50 Hertz
- Output voltage of 15VDC
- Target output voltage ripple of 100mVpk
- Maximum output current of 60mA
- Forward voltage drop of the freewheeling diode (D4)

The most useful output parameters of the design tool are:
- Input capacitor value (C1)
- Inductor value (L1)
- Feedback resistor value (R2)
- Feedback capacitor value (C2)
- Bias resistor value (R1)

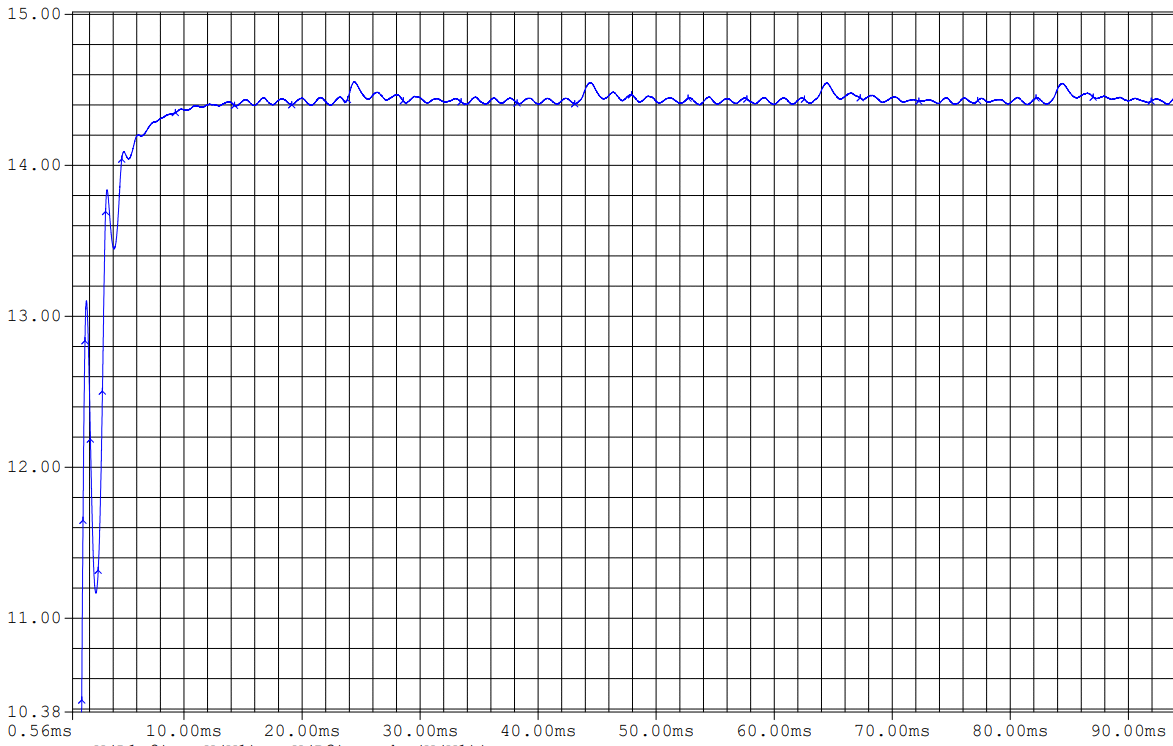
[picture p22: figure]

Figure 13: Output voltage of the LNK302 buck converter

As shown in figure 13, the output voltage ripple is about 14.51V − 14.42V = 90mV, which meets the requirements.

### 5.2.3 Zero-crossing circuit

This new simplified zero-crossing circuit consists of a voltage divider and an opamp used as a comparator. This circuit is chosen, because of its low cost and high availability of the components. A rail-to-rail single supply opamp is used to be able to create an output signal between 0 and 3.3V. The voltage divider attenuates the AC line signal from 253VRMS ×

√
2 ≈ 357Vpk to a voltage
within the range of the comparator (equation (4)). The current from the AC line leaking through resistors R5 and R6 and the power dissipated by the resistors is given by equation (5).

Vcomparator = Vin

R5
R5 + R6

= 357Vpk

82kΩ
10MΩ + 82kΩ ≈ 2.9Vpk | (4)

IACleak =

340
10MΩ + 82kΩ ≈ 34µA, | Presistors = (34µA)²
× (10MΩ + 82kΩ) ≈ 12mW | (5)

Figure 14: Attenuated AC line (red) and zero-crossing signal (green)

The zero-crossing signal is a square wave, which inverts every half AC-line cycle as shown in the simulation results (figure 14).

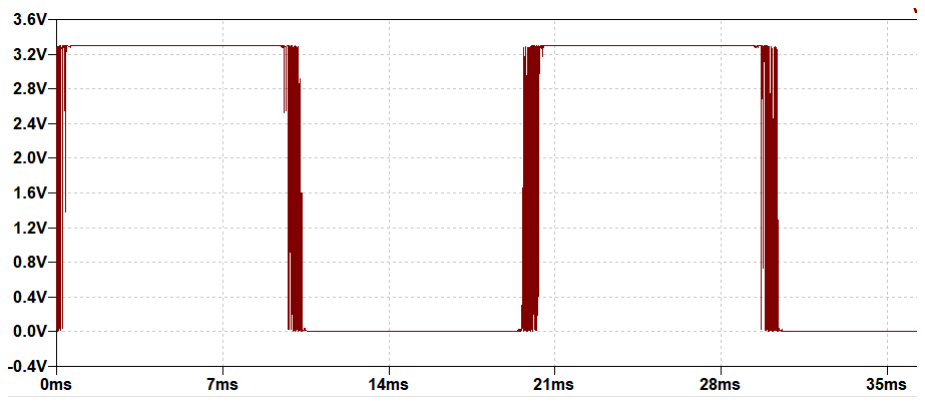
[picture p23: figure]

Figure 15: Bouncing output signal caused by noise

In the LT-Spice simulation, a perfect sine wave is used to simulate the detection of zero-crossings. However, the mains voltage isn’t an ideal sine wave because of the noise present on the power grid. This noise will result in the opamp output bouncing around the zero-crossing (figure 15). This bouncing signal will first be filtered by the firmware running on the MCU to detect a zero-crossing. Another option would be hardware filtering the signal, but the firmware option is preferred due to its flexibility.

5.2.4 3.3V DC/DC converter

To create a stable 3.3V for the SoC module in an efficient way, a second DC/DC step-down converter is used. LT1934-1 is chosen for its wide input voltage range of 3.2V - 32V [11], as well as its output current of 60mA and lastly its availability. Since the maximum power drawn by the SoC is 9.6mA, this will fit well within the specifications of the DC/DC converter.

Figure 16: Plot of the input current of the buck converter at the device (red) after the capacitor (blue)

Buck converters draw current from the input in short pulses with fast rise and fall times, as shown in figure 16. To reduce the current drawn from the output of the LNK302 power supply, input capacitor C5 of 1µF is added to the input of the device. [11]
At an output current of 45mA, the manufacturer recommends a minimal inductor value of 100µH.

COUT > 50 × L × (ILIM/VOUT)

2
(6)

The minimum output capacitance can be calculated using equation (6) The current limit of the switch in the LT1934-1 is 120mA, this solves for COUT > 6.6µF. Capacitor C7 is added to further reduce the output voltage ripple caused by the feedback comparator.

VOUT = 1.25V(1 + R3/R4) = 1.25V(1 + 1MΩ/620kΩ) = 3.27V | (7)

The output voltage is set by a voltage divider of R3 and R4 on the feedback pin (equation (7)). D6 is used as a flyback diode for the inductor. Here, a CMDSH2 Schottky diode is chosen for its reverse voltage rating of 30V, forward current rating of 200mA [5]and low forward voltage drop, resulting in higher efficiency of the buck converter due to less power dissipation in the diode.

Finally, D5 and C6 create a boost voltage higher than the input voltage. This voltage is used to drive the internal NPN switch of the device.

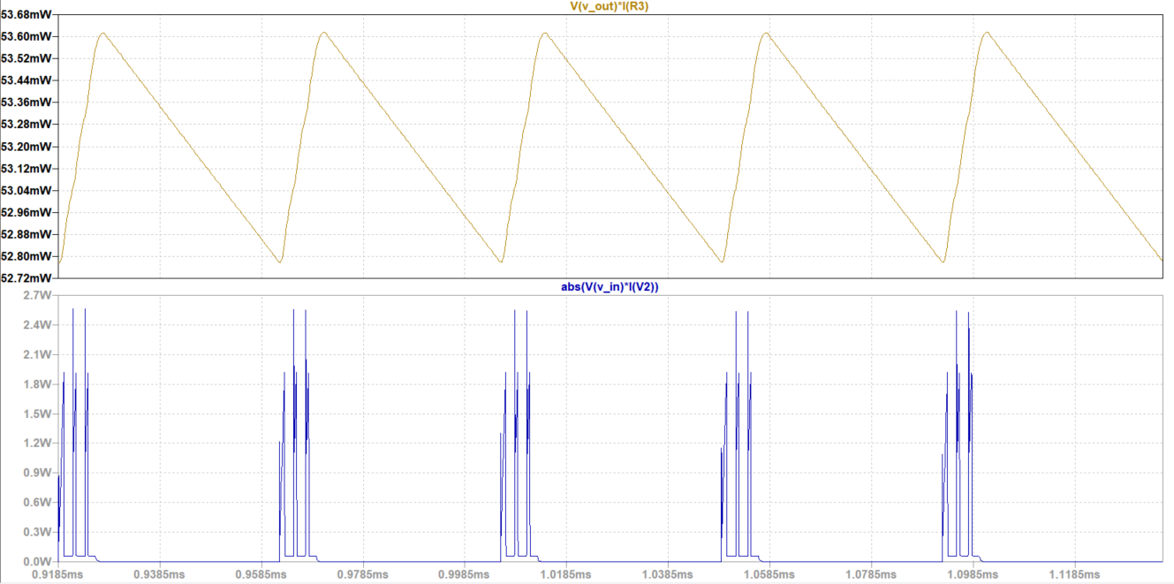
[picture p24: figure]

Figure 17: Plot of 5 periods of the output (top) and input (bottom) power

η =

POUT

PIN

=

53.2mW
73.8mW
= 72% | (8)

The efficiency of the step-down converter is given by equation (8), which uses the average in and output current computed by LTspice [6].

### 5.3 Microcontroller

To realize the microcontroller subsystem, a Nordic Semiconductor BLE SoC was chosen. This is a highly integrated SoC that contains a 2.4 GHz transceiver, a 32-bit ARM® Cortex™-M4F CPU, a 512 kB flash memory, 64 kB RAM as well as analog and digital peripherals (figure 18). Crownstone already uses the nRF52832 SoC which is running Bluenet, the in-house firmware for all Crownstone hardware.


Figure 18: Block diagram of the ACN52832 module Source: [2]

For the dimmer prototype, a fully integrated module featuring the nRF52832 SoC will be used: Aconno’s ACN52832 [2]. This module integrates Nordic’s nRF52832 BLE SoC, the accompanying PCB antenna with RF matching circuit, power supply decoupling capacitors, 32 MHz and 32.768 kHz crystals and load capacitors. This module also includes an RGB LED for optical feedback. For programming the MCU and debugging software, ARM’s 2-pin Serial Wire Debug (SWD) port and a UART connection are used. To be able to easily connect these pins, a debug connector is added to the board.

### 5.4 Dimmer

### 5.4.1 Selecting an IGBT

3.

### 5.4.2 Driving the IGBTs

4.

### 5.5 Connectors

Power connector

As stated in requirements NF-1 and NF-2 , since connectors need to fit solid core wires of multiple gauges, screw terminal blocks were chosen for making the power connections.
The power screw terminals must meet the following requirements:
- Minimal voltage rating of 253V RMS, REQ-1.1
- Minimal current rating of 10A, REQ-2.3, REQ-3.1
- Suitable for both 1.5mm² and 2.5mm²
cables, NF-1 , NF-2
- VDE safety certification, NFREQ-5
- 4 connections, REQ-1.2, REQ-1.3

A Phoenix Contact MKDSN 2.5/4 BK screw terminal is chosen based on these requirements. This component is rated for a nominal current of 16A, a nominal voltage of 400V, allows the connection of a 0.2mm²

to 2.5mm²
conductor and is VDE approved [16]. The power connector will have the following connections:
- Live
- Live
- Neutral
- Switched output

Debug connector

For compatibility, the debug connector will have the same pinout and PCB footprint as the debug connector found on the Crownstone Built-In devices. The connector itself is a surface mount ten pin, two-row header with a 2.54mm pitch [3].
The debug connector will have the following connections:
- Supply power: GND, 3V3
- UART: RXD, TXD
- SWD: Clock, IO
- Four GPIO pins

### 5.6 Interface

A potentiometer, as found on most dimmers, isn’t suitable for controlling the dimmer via both Bluetooth and a knob on the device. For this reason, a quadrature output rotary encoder is chosen.


Figure 19: Quadrature output of the rotary encoder [4]

A rotary encoder’s main advantage is its ability to rotate left and right unlimited, as well as it having a push switch.
The output signal of the rotary encoder consists of two square waves which are 90 degrees out of phase figure 19. This way the firmware on the microcontroller can detect a clockwise and counterclockwise rotation of the knob. If, for example, signal A leads signal B, the rotation is clockwise. For using the encoder as an input to the microcontroller, the common connection is connected to ground and the two switch outputs are pulled high to 3.3V via 10kΩ resistors. Between the output of the encoder and the microcontroller, an RC filter is added to filter the bouncing signal.

## 6 Test Phase

This section describes all unit test procedures and criteria and the results of the unit tests.

### 6.1 Power supply

The power supply unit test is split up into four tests. In unit tests 1.1 and 1.2, the DC/DC converters will be tested individually. Unit tests 1.3 and 1.4 test both buck converters as a whole. Unit test 1.5 will test only the zero-crossing circuit, unit test 1.6 tests the zero-crossing circuit as part of the whole system.

### 6.1.1 Unit test 1.1, 15V buck converter test

According to the datasheet [17], LNK302 is rated for a supply voltage as low as 50V DC. This lower voltage allows for safer testing of the circuit in a low voltage DC test.
In this test, two load resistors are used to simulate different current draws from the buck converter.
Tested requirements | REQ-1.2 The system shall be able to operate without the need of a neutral wire (2-wire). REQ-5.1 The product will shut down when the temperature gets too high. REQ-5.2 The product shall have overcurrent protection. REQNF-1 The connectors shall be suitable for solid core 2.5mm² ca-bles. REQNF-2 The connectors shall be suitable for solid core 1.5mm² ca-bles.
Required materials | Oscilloscope Bench DC power supply Multimeter Load resistors
Test criteria | The system will pass the test when: • The output voltage of the buck converter is between 14.5V and 15.5V DC • The maximum output voltage ripple is 100mV
Test procedure | Steps to test the unit:
1. Set the DC power supply to 60V DC by using the serial mode, set
| the current limit to 50mA
2. Connect the bench power supply to the unit
3. Set the oscilloscope to DC coupling, 5V/div, 250µs/div
4. Connect a load resistor of 1kΩ to the output of the unit
5. Connect the oscilloscope to the output of the system
6. Switch on the bench power supply
7. Measure the DC output voltage of the system
8. Set the oscilloscope to AC coupling, 100mV/div, 250µs/div
9. Connect the oscilloscope to the output of the system
10. Measure the output voltage ripple of the system
11. Repeat the test with a load resistor of 560Ω

Table 8: Unit test 1.1, 15V buck converter test

### 6.1.2 Test results unit test 1.1


(a) DC Coupling | (b) AC Coupling

Figure 20: Test results unit test 1.1, 1kΩ load resistor

The 1kΩ load resistor causes a current flow of 15mA at the output of the buck converter. Figure 21a shows the measurement made in step 6 of the test, the DC output voltage of the system. The voltage measured is between 14.6V and 15.4V, which meets the criteria of the test.
Figure 21b shows step 8 of the test, the measurement of the output voltage ripple (∆V). The measured voltage ripple is 94mV, which meets the criteria of the test.


(a) DC Coupling | (b) AC Coupling

Figure 21: Test results unit test 1.1, 560Ω load resistor

5.todo, testresultaten lnk302 met 560 ohm load

### 6.1.3 Unit test 1.2, 15V to 3.3V converter test

This unit test will test the second stage of the power supply, the 3.3V output.

Tested requirements | REQ-1.2 The system shall be able to operate without the need of a neutral wire (2-wire). REQ-5.1 The product will shut down when the temperature gets too high. REQ-5.2 The product shall have overcurrent protection. REQNF-1 The connectors shall be suitable for solid core 2.5mm² ca-bles. REQNF-2 The connectors shall be suitable for solid core 1.5mm² ca-bles.
Required materials | Oscilloscope Bench DC power supply Load resistor
Test criteria | The system will pass the test when: • The output voltage of the buck converter is between 3V and 3.3V DC • The maximum output voltage ripple is 100mVpp
Test procedure | Steps to test the unit: 1. Set the DC power supply to 15V DC, set the current limit to 50mA 2. Connect the bench power supply to the unit 3. Connect a 200Ω load resistor to the output of the unit 4. Set the oscilloscope to DC coupling, 1V/div, 25µs/div 5. Connect the oscilloscope to the output of the unit 6. Switch on the bench power supply 7. Measure the DC output voltage 8. Set the oscilloscope to AC coupling, 50mV/div, 25µs/div 9. Connect the oscilloscope to the output of the unit 10. Measure the output voltage ripple

Table 9: Unit test 1.2, 15V to 3.3V converter test

### 6.1.4 Test results unit test 1.2


(a) DC Coupling | (b) AC Coupling

Figure 22: Test results unit test 1.2

The 200Ω load resistor causes a current flow of 16.5mA at the output of the buck converter. This is similar to the current the microcontroller will draw.

By AC coupling the measured output, the DC component is filtered out of the signal, allowing for a better view of the voltage ripple. The measured voltage ripple (∆V) shown in figure 22b is 84mV, which is within the criteria of the test.

### 6.1.5 Unit test 1.3, low voltage DC test

This unit test will test both the first and second stages of the power supply. For safer testing, this test uses a low voltage DC source.

Tested requirements

Required materials | Oscilloscope Bench power supply Load resistors
Test criteria | The system will pass the test when: • The output voltage of the first buck converter is between 14.5V and 15.5V DC • The output voltage of the second buck converter is between 3V and 3.3V DC • The maximum output voltage ripple is 100mVpp
Test procedure | Steps to test the unit:
1. Set the DC power supply to 60V DC by using the serial mode, set
| the current limit to 50mA
2. Connect the bench power supply to the unit
3. Set the oscilloscope to DC coupling, 5V/div, 250µs/div
4. Connect a load resistor of 1kΩ to the output of the 15V buck converter
5. Connect a load resistor of 200Ω to the output of the 3.3V buck con-
| verter
6. Connect the oscilloscope to the output of the 15V buck converter
7. Switch on the bench power supply
8. Measure the DC output voltage of the 15V buck converter
9. Set the oscilloscope to DC coupling, 1V/div, 25µs/div
10. Connect the oscilloscope to the output of the 3.3V buck converter
11. Measure the DC output voltage of the 3.3V buck converter
12. Set the oscilloscope to AC coupling, 100mV/div, 250µs/div
13. Connect the oscilloscope to the output of the 15V buck converter
14. Measure the output voltage ripple of the 15V buck converter
15. Set the oscilloscope to AC coupling, 50mV/div, 25µs/div
16. Connect the oscilloscope to the output of the 3.3V buck converter
17. Measure the output voltage ripple of the 3.3V buck converter

Table 10: Unit test 1.3, low voltage DC test

### 6.1.6 Test results unit test 1.3

6.todo, tekst

Figure 23: Test results unit test 1.3, DC output voltage


(a) 15V buck converter | (b) 3.3V buck converter

Figure 24: Test results unit test 1.3, output voltage ripple

### 6.1.7 Unit test 1.4, AC supply test

To test the complete power supply, this test also tests the rectifier at the input stage.

### 6.1.8 Test results unit test 1.4

7.todo

Tested requirements | REQ-1.1 The system shall operate on a voltage between 207V and 253V RMS. REQ-1.2 The system shall be able to operate without the need of a neutral wire (2-wire). REQ-5.1 The product will shut down when the temperature gets too high. REQ-5.2 The product shall have overcurrent protection. REQNF-1 The connectors shall be suitable for solid core 2.5mm² ca-bles. REQNF-2 The connectors shall be suitable for solid core 1.5mm² ca-bles.
Required materials | Oscilloscope AC power supply or autotransformer Multimeter
Test criteria | The system will pass the test when: • The output voltage of the first buck converter is between 14.5V and 15.5V DC • The output voltage of the second buck converter is between 3V and 3.3V DC • The maximum output voltage ripple is 100mVpp
Test procedure | Steps to test the unit:
1. Set the AC power supply to 0V AC
2. Connect a multimeter in AC mode to the power supply
3. Connect the AC power supply to the unit
4. Set the oscilloscope to DC coupling, 5V/div, 250µs/div
5. Connect a load resistor of 1kΩ to the output of the 15V buck converter
6. Connect a load resistor of 200Ω to the output of the 3.3V buck con-
| verter
7. Connect the oscilloscope to the output of the 15V buck converter
8. Switch on the AC power supply and bring up the voltage to 100V AC
9. Measure the DC output voltage of the 15V buck converter
10. Set the oscilloscope to DC coupling, 1V/div, 25µs/div
11. Connect the oscilloscope to the output of the 3.3V buck converter
12. Measure the DC output voltage of the 3.3V buck converter
13. Set the oscilloscope to AC coupling, 100mV/div, 250µs/div
14. Connect the oscilloscope to the output of the 15V buck converter
15. Measure the output voltage ripple of the 15V buck converter
16. Set the oscilloscope to AC coupling, 50mV/div, 25µs/div
17. Connect the oscilloscope to the output of the 3.3V buck converter
18. Measure the output voltage ripple of the 3.3V buck converter

Table 11: Unit test 1.4, Power supply AC test

### 6.1.9 Unit test 1.5, zero-crossing detection

### 6.1.10 Test results unit test 1.5

Tested requirements | REQ-1.4 Zero-crossings of the AC line shall be detected. REQ-3.2 The relay shall be switched on a zero-crossing of the AC power.
Required materials | Oscilloscope Bench power supply Arbitrary waveform generator
Test criteria | The system will pass the test when: • The square wave toggles every time the input signal crosses 0V • The output voltage of the zero cross detector is between 0V and 3.3V
Test procedure | Steps to test the unit: 1. Set the DC power supply to 3.3V DC, set the current limit to 50mA 2. Connect the power supply to the unit 3. Set the arbitrary waveform generator to a sine wave of 8Vpp at a frequency of 50Hz 4. Set channel 1 of the oscilloscope to AC coupling, 2V/div, channel 2 to DC coupling, 1V/div, 10ms/div 5. Connect channel 1 of the oscilloscope to the output of the waveform generator and channel 2 to the output of the unit to measure the output voltage 6. Measure the voltage of the square wave

Table 12: Unit test 1.5, zero-crossing detection


(a) Input (red) and output (blue) | (b) Output measurement

Figure 25: Test results unit test 1.5

### 6.1.11 Unit test 1.6, complete power supply test

### 6.1.12 Test results unit test 1.5

Tested requirements | REQ-1.4 Zero-crossings of the AC line shall be detected. REQ-3.2 The relay shall be switched on a zero-crossing of the AC power.
Required materials | Oscilloscope Bench power supply Arbitrary waveform generator
Test criteria | The system will pass the test when: • The square wave toggles every time the input signal crosses 0V • The output voltage of the zero-cross detector is between 0V and 3.3V
Test procedure | Steps to test the unit: 1. Set the DC power supply to 3.3V DC, set the current limit to 50mA 2. Connect the power supply to the unit 3. Set the arbitrary waveform generator to a sine wave of 8Vpp at a frequency of 50Hz 4. Set channel 1 of the oscilloscope to AC coupling, 2V/div, channel 2 to DC coupling, 1V/div, 10ms/div 5. Connect channel 1 of the oscilloscope to the output of the waveform generator and channel 2 to the output of the unit to measure the output voltage 6. Measure the voltage of the square wave

Table 13: Unit test 1.6, complete power supply test

(a) Input (red) and output (blue) | (b) Output measurement

Figure 26: Test results unit test 1.5

### 6.2 Microcontroller

### 6.2.1 Unit test 2.1, NAAM

### 6.2.2 Test results unit test 2.1

Tested requirements | REQ-1.4 Zero-crossings of the AC line shall be detected. REQ-3.2 The relay shall be switched on a zero-crossing of the AC power.
Required materials | Oscilloscope Bench power supply Arbitrary waveform generator Test code
Test criteria | The system will pass the test when: •
Test procedure | Steps to test the unit: 1.

Table 14: Unit test 2.1, NAAM

### 6.3 Dimmer

### 6.3.1 Unit test 3.1, NAAM

Tested requirements | REQ-1.4 Zero-crossings of the AC line shall be detected. REQ-3.2 The relay shall be switched on a zero-crossing of the AC power.
Required materials | Oscilloscope Bench power supply Arbitrary waveform generator
Test criteria | The system will pass the test when: •
Test procedure | Steps to test the unit: 1.

Table 15: Unit test 3.1, NAAM

### 6.3.2 Test results unit test 3.1

### 6.4 Integration Tests

### 6.4.1 Power supply and microcontroller

Tested requirements

Required materials | Oscilloscope Bench power supply Test code
Test criteria | The system will pass the test when: •
Test procedure | Steps to test the unit: 1.

Table 16: Integration test 1, NAAM

## References

[1] Dimming leds - the difference between leading and trailing edge. 2015.
[2] Aconno. Datasheet ACN52832 V1.2, 8 2019.
[3] Amphenol ICC. Econostik Header .100/2.54 DR SMT, 4 2014.
[4] Bourns. PEC12R - 12 mm Incremental Encoder, 7 2021.
[5] Central Semiconductor. Datasheet High Current Schottky Diode.
[6] Analog | Devices. | Lt | spice. | https://www.analog.com/en/design-center/
design-tools-and-calculators/ltspice-simulator.html, (https://www.analog.com/en/design-center/design-tools-and-calculators/ltspice-simulator.html) 1998–2021.
[7] Eaton. Technical data 10554: TV Supercapacitors Cylindrical cells, 8 2016.
[8] Himax Electronics. Basics about discharging. 8 2021.
[9] Manoj Gulati, Farshid Salemi Parizi, Eric Whitmire, Sidhant Gupta, Shobha Sundar Ram, Amarjeet Singh, and Shwetak N Patel. Capharvester: A stick-on capacitive energy harvester using stray electric field from ac power lines. Proceedings of the ACM on Interactive, Mobile, Wearable and Ubiquitous Technologies, 2(3):1–20, 2018.
[10] Power Integrations. Design example report 832 - two-wire (no neutral), wide-range, isolated flyback, bluetooth wall switch. (DER-832), 9 2019.
[11] Linear Technology. Datasheet Micropower Step-Down Switching Regulators.
[12] ST Microelectronics. Steval-ild004v2: leading-edge dimmer user manual. (UM1908), 3 2015.
[13] Nordic Semiconductor. Online Power Profiler for BLE.
[14] Nordic Semiconductor. nRF52832 Product Specification, 8 2021.
[15] Panasonic. Small Polarized Power Relay, 5 2021.
[16] Phoenix Contact. PCB Terminal Block MKDSN 2,5/4 BK, 5 2018.
[17] Power Integrations. Datasheet LNK302/304-306 LinkSwitch-TN Family, 6 2013.
[18] Power Integrations. Datasheet LNK33x2-7D LinkSwitch-TNZ Family, 6 2021.
[19] Renata Batteries. Rechargeable Lithium Ion Polymer Battery Pack 3.7 V, 10 2019.
[20] RS. 3.6V NiMh Rechargeable Coin Cell Battery.
[21] Evans Sordiashie. Electromagnetic harvesting to power energy management sensors in the built environment. 2012.
[22] Texas Instruments. Datasheet LP2985 150-mA Low-noise Low-dropout Regulator With Shutdown, 1 2015.

## Glossary

LTE-M Long Term Evolution - Machine Type Communication, a low power wide-area network radio technology. 5

NB-IoT Narrowband Internet of Things, a low power wide-area network radio technology. 5

soft-fuse A passive electronic device used to protect against over-current in electronics. 5

standby-killer An electronic device that cuts electricity to devices that are in standby. 5

Thread A low power, IPv6 based, wireless mesh network protocol. 5

VDE German organization: Association for Electrical, Electronic & Information Technologies. An institute for testing and certification of electrical products.. 23

X-capacitor Safety rated capacitors, designed to be used in AC line filtering. 17

Zigbee A low power wireless mesh network protocol. 5

## Acronyms

BLE Bluetooth Low Energy. 5, 8, 22, 23

GPIO General Purpose Input/Output. 15

IGBT Insulated-gate bipolar transistor. 17

LDO Low Dropout Regulator. 18

LiPo Lithium-polymer. 3, 8, 9, 11

NiMH Nickel-Metal hydride. 3, 8, 9, 11

PWM Pulse Width Modulation. 15

SiP System-in-Package. 5

SoC System-on-Chip. 5, 7, 8, 11, 12, 15, 17, 18, 21, 22, 23

SWD Serial Wire Debug. 12, 15

UART Universal Asynchronous Receiver-Transmitter. 15, 23

## A Schematic V1


## B Schematic V1.3


Crownstone 2-wire BLE Dimmer

DRAWING
Power Supply, Zero Crossing, SoC

## C PI Expert LinkSwitch-TNZ Buck converter design

ACDC_LinkSwitchTNZ_Buck_05262 1; Rev.1.0; Copyright Power Integrations 2021 | INPUT | INFO | OUTPUT | UNIT | ACDC LinkSwitch-TNZ Buck
ENTER APPLICATION VARIABLES | | | | | Design Title
LINE VOLTAGE RANGE | | | High Line | | AC line voltage range
VACMIN | 207.00 | | 207.00 | V | Minimum AC line voltage
VACMAX | 253.00 | | 253.00 | V | Maximum AC line voltage
fL | 50.00 | | 50.00 | Hz | AC mains frequency
LINE RECTIFICATION TYPE | H | | H | | Line rectification type: select "F" if full wave rectification or "H" if half wave rectification
VOUT | 15.00 | | 15.00 | V | Output voltage
IOUT | 0.080 | | 0.080 | A | Average output current
EFFICIENCY_ESTIMATED | | | 0.80 | | Efficiency estimate at output terminals
EFFICIENCY_CALCULATED | | | 0.84 | | Calculated efficiency based on real components and operating point
POUT | | | 1.20 | W | Continuous output power
CIN | 3.30 | | 3.30 | uF | Input capacitor
VMIN | | | 263.5 | V | Valley voltage of the rectified minimum AC line voltage
VMAX | | | 357.8 | V | Peak voltage of the maximum AC line voltage
INPUT STAGE RESISTANCE | 5 | | 5 | Ohms | Input stage resistance in ohms (includes thermistor, filtering components, etc)
PLOSS_INPUTSTAGE | | | 0.000 | W | Maximum input stage loss

ENTER LINKSWITCH-TNZ VARIABLES

OPERATION MODE | | MCM | | Mostly continuous mode of operation
CURRENT LIMIT MODE | STD | STD | | Choose 'RED' for reduced current limit or 'STD' for standard current limit
XCAP REQUIRED | YES | YES | | Select whether an X-capacitor is required or not
PACKAGE | | SO-8C | | Device package
DEVICE SERIES | LNK3312 | LNK3312 | | Generic LinkSwitch-TNZ device
DEVICE CODE | | LNK3312D | | Required LinkSwitch-TNZ device
ILIMITMIN | | 0.126 | A | Minimum current limit of the device
ILIMITTYP | | 0.136 | A | Typical current limit of the device
ILIMITMAX | | 0.146 | A | Maximum current limit of the device
RDSON | | 88.40 | ohms | Primary switch on-time drain to source resistance at 100degC
FSMIN | | 62000 | Hz | Minimum switching frequency
FSTYP | | 66000 | Hz | Typical switching frequency
FSMAX | | 70000 | Hz | Maximum switching frequency
BVDSS | | 725 | V | Device breakdown voltage

SWITCH PARAMETERS

VDSON | 2.00 | V | Switch on-time drain to source voltage estimate
VDSOFF | 375.7 | V | Switch off-time drain-to-source voltage stress
DUTY | 0.063 | | Maximum duty cycle
TIME_ON_MIN | 1.947 | us | Switch minimum on-time
IPED_SWITCH | 0.037 | A | Maximum switch pedestal current
IRMS_SWITCH | 0.022 | A | Maximum switch RMS current

PLOSS_SWITCH | 0.078 | W | Maximum switch loss
THERMAL RESISTANCE OF SWITCH | 100 | degC/W | Net thermal resistance of the switch
T_RISE_SWITCH | 7.8 | degC | Maximum temperature rise of the switch in degrees Celsius

BUCK INDUCTOR PARAMETERS

INDUCTANCE_MIN | | 7380 | uH | Minimum design inductance required for current delivery
INDUCTANCE_TYP | 8200 | 8200 | uH | Typical design inductance required for current delivery
INDUCTANCE_MAX | | 9020 | uH | Maximum design inductance required for current delivery
TOLERANCE_INDUCTANCE | 10 | 10 | % | Tolerance of the design inductance
DC RESISTANCE OF INDUCTOR | 1.1 | 1.1 | ohms | DC resistance of the buck inductor
FACTOR_KLOSS | | 0.50 | | Factor that accounts for "off-state" power loss to be supplied by inductor (usually between 50% to 66%)
IRMS_INDUCTOR | | 0.088 | A | Maximum inductor RMS current
PLOSS_INDUCTOR | | 0.009 | W | Maximum inductor losses

FREEWHEELING DIODE PARAMETERS

VF_FREEWHEELING | 1.50 | 1.50 | V | Forward voltage drop across the freewheeling diode
PIV_RATING | | 600.0 | V | Peak inverse voltage rating of the freewheeling diode
TRR | | 30 | ns | Reverse recovery time of the freewheeling diode
PIV_CALCULATED | | 447.2 | V | Computed peak inverse voltage across the freewheeling diode
IRMS_DIODE | | 0.086 | A | Maximum diode RMS current
PLOSS_DIODE | | 0.132 | W | Maximum freewheeling diode loss
RECOMMENDED DIODE | | BYV26C | | Recommended freewheeling diode

BIAS/FEEDBACK PARAMETERS

VF_BIAS | 1.10 | 1.10 | V | Forward voltage drop of the bias diode
RBIAS | 2400 | 2400 | Ohms | Bias resistor (connected across FB and S pin). Results into IFB_BIAS value of 833.333 uA
RBP | | 140000 | Ohms | BP pin resistor
CBP | | 0.1 | uF | BP pin capacitor
RFB | | 15000 | Ohms | Feedback resistor
CFB | | 10 | uF | Feedback capacitor
C_SOFTSTART | | 1-10 | uF | If the output voltage is greater than 12 V or total output and system capacitance is greater than 100 uF, a soft start capacitor between 1uF and 10 uF is recommended
PLOSS_FEEDBACK | | 0.013 | W | Maximum feedback component losses

X-CAPACITOR DISCHARGE COMPONENTS

XCAP | | 100.0 | nF | X-capacitor in the input
TOLERANCE_RZ | 0.05 | 5% | | Tolerance of the X-capacitor discharge resistors
RZ1 | | 2.37 | MOhms | X-capacitor discharge resistor connected from the input line to Z1 pin of LinkSwitch-TNZ device

RZ2 | 2.37 | MOhms | X-capacitor discharge resistor connected from the input neutral to Z2 pin of LinkSwitch-TNZ device
t_XCAP_DISCHARGE | 0.889 | sec | Actual time (worst-case) to discharge the X-capacitor to 60 V after AC input disconnection

OUTPUT CAPACITOR

OUTPUT VOLTAGE RIPPLE | 300 | mV | Desired output voltage ripple
IRMS_COUT | 0.037 | A | Maximum output capacitor RMS current
PLOSS_COUT | 0.005 | W | Maximum output capacitor power loss
ESR_COUT | 3510 | mOhms | ESR of the output capacitor

## D PI Expert LinkSwitch-TN Buck converter design

## E Competentieverantwoording

8.todo, competentieverantwoording

## F Reflectie

9.todo, reflectie

## G Tussentijdse beoordeling

# Tussenbeoordeling bedrijfsbegeleider stage

Geachte bedrijfsbegeleider,
Uw tussentijdse beoordeling van de stagiair is voor belangrijke input voor zijn/haar ontwikkeling. Daarom vragen wij u dit formulier halverwege de stage in te vullen en met de stagiair te bespreken. Kruist u de punten aan die van toepassing zijn. Voor extra op- en aanmerkingen hebben we ook ruimte gelaten. Hartelijk dank voor uw medewerking.
Bedrijfsbegeleider: Dr. Ir. A. C. van Rossum | Bedrijf: Crownstone
Naam student: Jaap Sontrop | Studentnr: 0989157

## A. ANALYSEREN, ONTWERPEN, REALISEREN en BEHEREN

1: ontbrekend of onvoldoende
| 2: vraagt nog wat aanpassing of toevoeging
3: redelijk
4: goed

ANALYSEREN
1 / 2 / 3 / 4 - het programma van eisen is een onderbouwde technische vertaling van de wensen van de opdrachtgever;
1 / 2 / 3 / 4 - de probleemstelling komt overeen met de opdracht/de doelstelling is conform de eisen van de opdrachtgever;
1 / 2 / 3 / 4 - er is afweging gemaakt voor mogelijke oplossingsrichtingen op essentiële momenten;

Opmerkingen: Voorbeelden van afwegingen zijn bijv. de keuze voor de voeding of voor de nuldoorgangsmeting.

ONTWERPEN
1 / 2 / 3 / 4 - het ontwerp voldoet aan de kwaliteitseisen van het bedrijf;

Opmerkingen: Ziet er tot nog toe goed uit, maar het gehele ontwerp is nog niet af. Dus te vroeg.

REALISEREN
1 / 2 / 3 / 4 - het product/de simulatie is als geheel testbaar;
1 / 2 / 3 / 4 - er is vastgesteld of het product al dan niet aan de eisen voldoet die zijn meegenomen in het ontwerp; 1 / 2 / 3 / 4 - de testen zijn conform de gekozen ontwerpmethodiek uitgevoerd;

Opmerkingen: Dit is 50% beoordeling. Dit is nog te vroeg.

BEHEREN
1 / 2 / 3 / 4 - er is een gebruiks-, onderhouds- en/of inbedrijfstellingshandleiding opgesteld; 1 / 2 / 3 / 4 - de projectdocumentatie is volledig en volgens de bedrijfsconventies opgesteld.

Opmerkingen: Dit is 50% beoordeling. Te vroeg voor handleidingen. Documentatie kan wel beter (ook in dit stadium).

## B. MANAGEN, ONDERZOEKEN, PROFESSIONALISEREN en ADVISEREN

MANAGEN
1 / 2 / 3 / 4 - het plan van aanpak bevat alle noodzakelijke onderdelen en is systematisch uitgewerkt; 1 / 2 / 3 / 4 - er is een uitgewerkte planning vastgelegd;
1 / 2 / 3 / 4 - alle mogelijke risico’s zijn in kaart gebracht;
1 / 2 / 3 / 4 - de planning en risico's zijn tussentijds geëvalueerd;
1 / 2 / 3 / 4 - de stakeholders van het project zijn op de hoogte gehouden van de planning en voortgang;
1 / 2 / 3 / 4 - de student heeft de projectdocumentatie verzorgd volgens de binnen het bedrijf geldende normen;

Opmerkingen: Planning is goed vastgelegd, maar kan (incl. risico's) meer proactief met de begeleider worden doorgenomen.

ONDERZOEKEN
1 / 2 / 3 / 4 - op relevante momenten werd benodigde data verkregen door
onderzoek dan wel uit betrouwbare bronnen;

Opmerkingen: Er wordt beide theoretisch gezocht en empirisch gecontroleerd. Communiceren over de betrouwbaarheid van desbetreffende data kan nog wel beter.

PROFESSIONALISEREN
1 / 2 / 3 / 4 - er is effectief met de opdrachtgever en bedrijfsbegeleider gecommuniceerd;
1 / 2 / 3 / 4 - de student heeft cruciale feedback van bedrijfsbegeleider aangenomen of met
onderbouwing verworpen;
1 / 2 / 3 / 4 - de zelfstandigheid van de student en vragen aan de bedrijfsbegeleider waren in de juiste balans; 1 / 2 / 3 / 4 - potentiële problemen en fouten zijn voorkomen door tijdige reflectie op handelen en omstandigheden;
1 / 2 / 3 / 4 - de student heeft besluiten genomen conform de maatschappelijke normen;
1 / 2 / 3 / 4 - de student heeft effectief gehandeld en gecommuniceerd in een internationale, multidisciplinaire en/of interdisciplinaire werkomgeving.

Opmerkingen: Communicatie is goed, maar ik kan nog beter inzicht krijgen in potentiele problemen en zou meer vragen verwachten.

ADVISEREN
1 / 2 / 3 / 4 - tijdens het proces heeft de student aan de opdrachtgever waardevolle adviezen gegeven;
1 / 2 / 3 / 4 - de adviezen over vervolgstappen om het gerealiseerde ontwerp te verbeteren zijn volledig en eenduidig.

Opmerkingen: Te vroeg

C. TOT SLOT

Welke advies wilt u de student meegeven voor het verder verloop van de stage?

Communiceer proactief. Email meer met Peet met mij in CC. Neem mensen mee in je denkproces.

Beoordelaar:
Datum: Handtekening:

PS: de student voegt dit ondertekende formulier als bijlage toe aan zijn/haar definitieve stageverslag.

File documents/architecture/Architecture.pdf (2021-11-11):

## 1 Architecture phase

In this chapter the structure of the system will be described. When describing the architecture, subsystems and the connections between them will be defined.

### 1.1 Context diagram

The context diagram in Figure 1 shows how the external sources interact with the system.

1.add text to describe the figure


Figure 1: Context diagram

### 1.2 Architecture Interconnect Diagram

The architecture interconnect diagram (Figure 2) gives a more detailed overview of the system. This diagram shows the connections between the three subsystems (Power supply, Microcontroller and Dimmer) and their external connections as shown in Figure 1.


Figure 2: Architecture interconnect diagram

### 1.3 Subsystems

The system consists of three subsystems, the following sections will briefly describe these three subsystems and the data flows between them.

### 1.3.1 Power supply

The power supply contains four parts: a half wave rectifier, DC to DC power converters and zero-crossing detection.
This subsystem provides power at the right voltage for the gate driver and microcontroller. The zero-crossing system will supply a square wave signal to the microcontroller.

### 1.3.2 Microcontroller

The microcontroller is part of the SoC which handles the Bluetooth communication and ensures that all subsystems are connected. It receives the zero crossing detection signal from the power supply, detects use of the rotary knob and sends a PWM signal to the dimmer system.
External connections to the microcontroller for debug purposes are: UART, Serial Wire Debug, four GPIO pins and the ability to power the microcontroller from an external power source.

### 1.3.3 Dimmer

The dimmer is responsible for generating the phase cut output signal from a PWM signal derived from the microcontroller.
This subsystem consists of two semiconductors for phase cutting the output signal and a gate driver to drive the semiconductors.

### 1.4 Traceability of requirements

The Requirements traceability matrix shows which subsystem is responsible for a requirement.

| Power supply | Microcontroller | Dimmer
REQ-1.1 | X | | X
REQ-1.2 | X | | X
REQ-1.3 | X
REQ-1.4 | X | X
REQ-2.1 | | X | X
REQ-2.2 | | X | X
REQ-2.3 | X | | X
REQ-2.4 | | | X
REQ-2.5 | | X
REQ-2.6 | | X
REQ-3.1 | 2.todo
REQ-3.2 | | X
REQ-4.1 | | X
REQ-4.2 | | X
REQ-4.3 | | X
REQ-5.1 | X | | X
REQ-5.2 | X
NFREQ-1 | X
NFREQ-2 | X
NFREQ-3 | X | X | X

Table 1: Requirements traceability matrix

### 1.5 Data dictionary

The data dictionary shows the connections as displayed in the architecture interconnect diagram (Figure 2), Table 2 shows a description of the flow, the unit and range.

Data flow | Description | Unit | Range
Power supply:
Zero crossing signal | High-low transitioning signal | Volts | 0 - 3.3
Power input | Mains AC power input | Volts (RMS) | 207 - 253
Microcontroller:
Dimmer value: knob | 0 - 100%
Dimmer value: Bluetooth | 0 - 100%
Dimmer:
PWM dimming signal | Signal from the microcontroller to the dimmer | Duty cycle | 0 - 100%
Dimmer output | Phase cut AC power from the dimmer to the light | Duty cycle | 0 - 100%
Debug connector:
UART | Receive, Transmit | Baud | 3.rate
SWD | Clock, I/O | - | -
GPIO | General purpose IO for debugging | - | -
3V3, GND | External MCU 3V3 power input | Volts | 3.0 - 3.6

Table 2: Data dictionary

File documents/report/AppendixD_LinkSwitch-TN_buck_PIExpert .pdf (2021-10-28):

ACDC_LinkSwitch-TN_042413; Rev.2.6; Copyright Power Integrations 2007 | INPUT | INFO | OUTPUT | UNIT | LinkSwitch-TN_Rev_2-6.xls: LinkSwitch-TN Design Spreadsheet
INPUT VARIABLES | | | | | Customer
VACMIN | 207 | | | Volts | Minimum AC Input Voltage
VACMAX | 253 | | | Volts | Maximum AC Input Voltage
FL | 50 | | | Hertz | Line Frequency
VO | 15.00 | | | Volts | Output Voltage
IO | 0.063 | | | Amps | Output Current
EFFICIENCY (User Estimate) | 0.72 | | | | Overall Efficiency Estimate (Adjust to match Calculated, or enter Measured Efficiency)
EFFICIENCY (Calculated Estimate) | | | 0.78 | | Calculated % Efficiency Estimate
CIN | 100.00 | | 100.00 | uF | Input Filter Capacitor
Input Stage Resistance | | | 0.00 | ohms | Input Stage Resistance, Fuse & Filtering
Ambient Temperature | | | 50 | deg C | Operating Ambient Temperature (deg Celsius)
Switching Topology | | | Buck | | Type of Switching topology
Input Rectification Type | H | | H | | Choose H for Half Wave Rectifier and F for Full Wave Rectification

DC INPUT VARIABLES

VMIN | 292.0 | Volts | Minimum DC Bus Voltage
VMAX | 357.8 | Volts | Maximum DC Bus Voltage

LinkSwitch-TN

LinkSwitch-TN | LNK302 | LNK302 | | Selected LinkSwitch-TN. Ordering info - Suffix P/G indicates DIP 8 package; suffix D indicates SO8 package; second suffix N indicates lead free RoHS compliance
ILIMIT | | 0.136 | Amps | Typical Current Limit
ILIMIT_MIN | | 0.126 | Amps | Minimum Current Limit
ILIMIT_MAX | | 0.146 | Amps | Maximum Current Limit
FSMIN | | 62000 | Hertz | Minimum Switching Frequency
VDS | | 12.0 | Volts | Maximum On-State Drain To Source Voltage drop
PLOSS_LNK | | 0.17 | Watts | Estimated LinkSwitch-TN losses

DIODE

VD | 0.98 | 0.98 | Volts | Freewheeling Diode Forward Voltage Drop
VRR | | 600 | Volts | Recommended PIV rating of Freewheeling Diode
IF | | 1 | Amps | Recommended Diode Continuous Current Rating
TRR | | 75 | ns | Recommended Reverse Recovery Time
Diode Recommendation | | UF4005 | | Suggested Freewheeling Diode

OUTPUT INDUCTOR

L_TYP | | 2560.0 | uH | Required value of Inductance to deliver Output Power (Includes device and inductor tolerances) Choose next higher standard available value
L | | 2700 | uH | Output Inductor, Recommended Standard Value
L_R | 6.0 | 6.0 | Ohms | DC Resistance of Inductor
OPERATING MODE | | MDCM | | Mostly Discontinuous Conduction Mode (at VMIN)
KL_TOL | | 1.15 | | Inductor tolerance Factor. Accounts for basic (10% -20%) Manufacturing Tolerances 1.1 < KL_TOL < 1.2 See AN-37 for detailed explanation

K_LOSS | 0.813 | | Loss factor. Accounts for "off-state" power loss to be supplied by inductor Calculated efficiency < K_LOSS <
1. See AN-37 for detailed explanation
ILRMS | 0.07 | Amps | Estimated RMS inductor current (at VMAX)

OUTPUT CAPACITOR

DELTA_V | 0.10 | 0.10 | Volts | Target Output Voltage Ripple
MAX_ESR | | 794 | m-Ohms | Maximum Capacitor ESR (milli-ohms)
I RIPPLE | | 0.13 | Amps | Output Capacitor Ripple current

FEEDBACK COMPONENTS

RBIAS | 2.00 | k-Ohms | Bias Resistor. Use closest standard 1% value
RFB | 15.29 | k-Ohms | Feedback Resistor. Use closest standard 1% value
CFB | 10 | uF | Feedback Capacitor
C_SOFT_START | 1 - 10 | uF | If the output Voltage is greater than 12 V, or total output and system capacitance is greater than 100 uF, a soft start capacitor between 1uF and 10 uF is recommended. See AN-37 for details

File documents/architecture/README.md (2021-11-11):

# Architecture

## Diagrams
All diagrams are made using the free online diagram software [draw.io](app.diagrams.net).

The context diagram gives a global overview of the system:

CD

The architecture interconnect diagram shows all subsystems and the connections between them.

AID

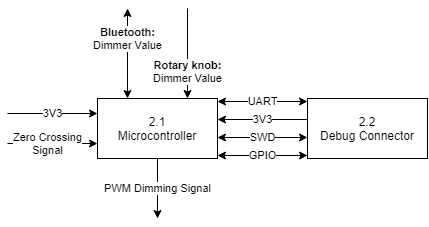
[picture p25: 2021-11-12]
documents/architecture/dfd2.png

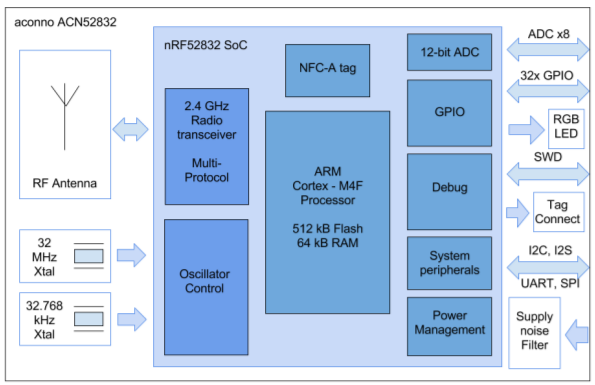
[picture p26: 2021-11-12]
documents/design/block_diagram_acn52832.PNG

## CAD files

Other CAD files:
hardware/PCB/board_outline.dwg

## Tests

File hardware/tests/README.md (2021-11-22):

# LNK302 buck converter

LinkSwitch-TN series DC/DC converter ICs combine a on/off controller and an integrated switch. LNK302 is used in a buck topology with direct feedback [(datasheet)](https://ac-dc.power.com/sites/default/files/product-docs/an37.pdf).\
[LNK302 buck converter simulation](https://github.com/doodeca/crownstone-2wire-dimmerswitch/blob/main/hardware/simulations/Pspice/README.md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)

## Test setup

Schematic

For safety, V1 is replaced by a 60V DC source. \
Diode D1 and capacitor C3 are bypassed, since the input already is a DC source.

## Test results

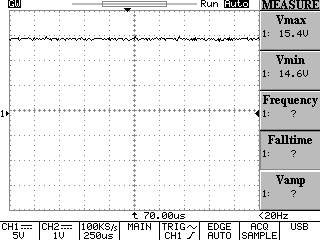
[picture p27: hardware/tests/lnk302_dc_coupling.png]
Output
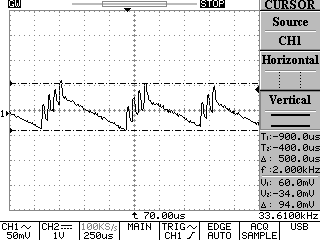
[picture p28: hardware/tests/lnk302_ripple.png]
Output ripple
&emsp;&emsp;

The left plot shows the output voltage of the buck converter.\
In the right plot the ripple on the output voltage is shown in more detail.

# LT1934-1 buck converter

LT1934-1 is a step-down DC/DC converter IC with an integrated switch, able to supply up to 60mA of output current. [(datasheet)](https://www.analog.com/media/en/technical-documentation/data-sheets/1934fe.pdf)\
[LT1934-1 buck converter simulation](https://github.com/doodeca/crownstone-2wire-dimmerswitch/blob/main/hardware/simulations/LTspice/README.md)

## Test setup

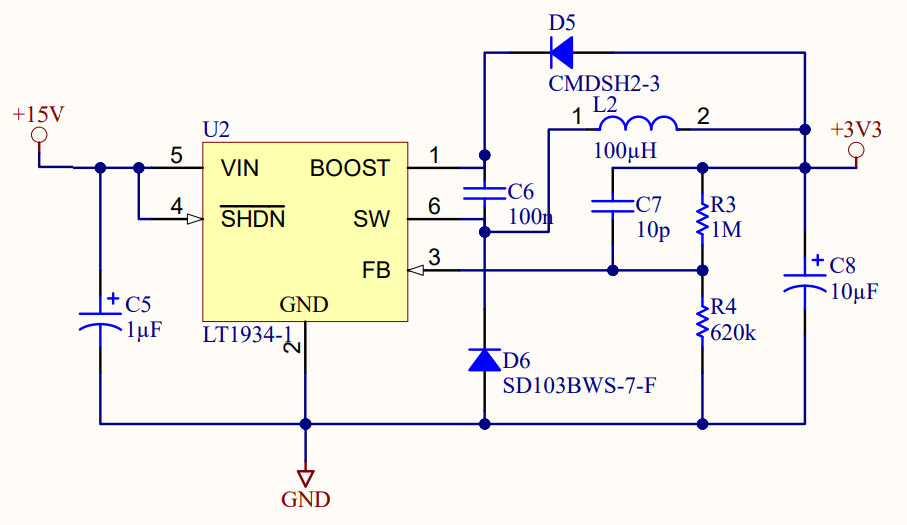
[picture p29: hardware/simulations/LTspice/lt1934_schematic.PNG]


Between the 3.3V output and GND, a 200 Ohm resistor is added as a load. 

## Test results

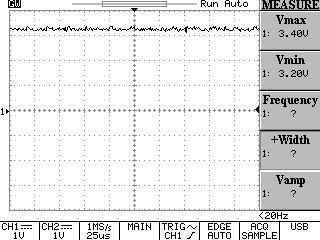
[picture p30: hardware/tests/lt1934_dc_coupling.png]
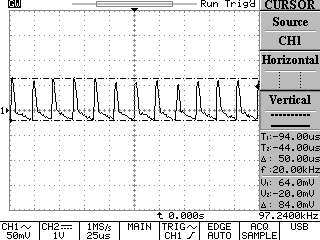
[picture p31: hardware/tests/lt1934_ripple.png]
&emsp;&emsp;

The left plot shows the output voltage of the buck converter.\
In the right plot the ripple on the output voltage is shown in more detail.

# Zero Cross Detection

The zero cross detector is a circuit that creates a square wave which toggles every half AC line cycle. The circuit consists of a voltage divider and a rail-to-rail opamp.\
[Zero cross detector simulation](https://github.com/doodeca/crownstone-2wire-dimmerswitch/blob/main/hardware/simulations/Pspice/README.md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)

## Test setup

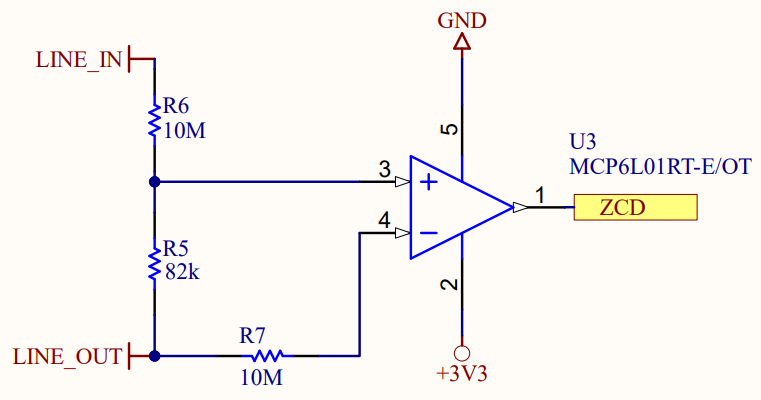
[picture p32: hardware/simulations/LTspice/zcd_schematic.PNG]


For safety, the AC source is changed to a 12V sine from the waveform generator. \
Since the input voltage has changed, resistors R5 - R7 of the resistor divider need different values. R5 had changed to 33k, R6 and R7 get a value of 100k. This way the voltage over R5 will be roughly 3V.\
U3 is replaced by OPA705, a generic rail-to-rail opamp in a more convenient dip package. [(datasheet)](https://www.ti.com/lit/ds/symlink/opa705.pdf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)
The power supply for the opamp (3.3V DC) will be supplied by a bench power supply.

## Test results

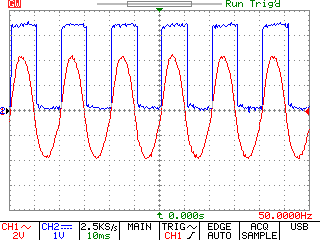
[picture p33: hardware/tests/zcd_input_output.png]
\

The red trace shows the input signal for the opamp.\
The blue trace shows the square wave output signal of the opamp.

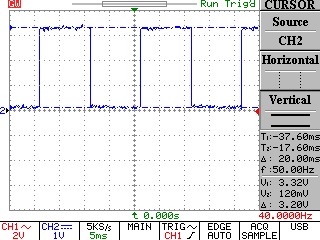
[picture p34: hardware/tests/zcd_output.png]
\

This plot shows a measurement of the output of the opamp.

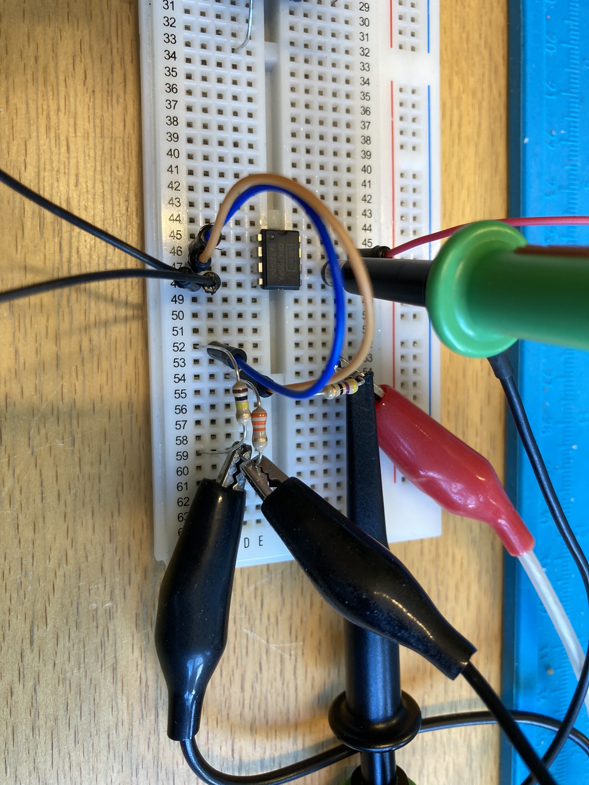
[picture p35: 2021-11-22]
hardware/tests/zcd_testsetup.jpeg

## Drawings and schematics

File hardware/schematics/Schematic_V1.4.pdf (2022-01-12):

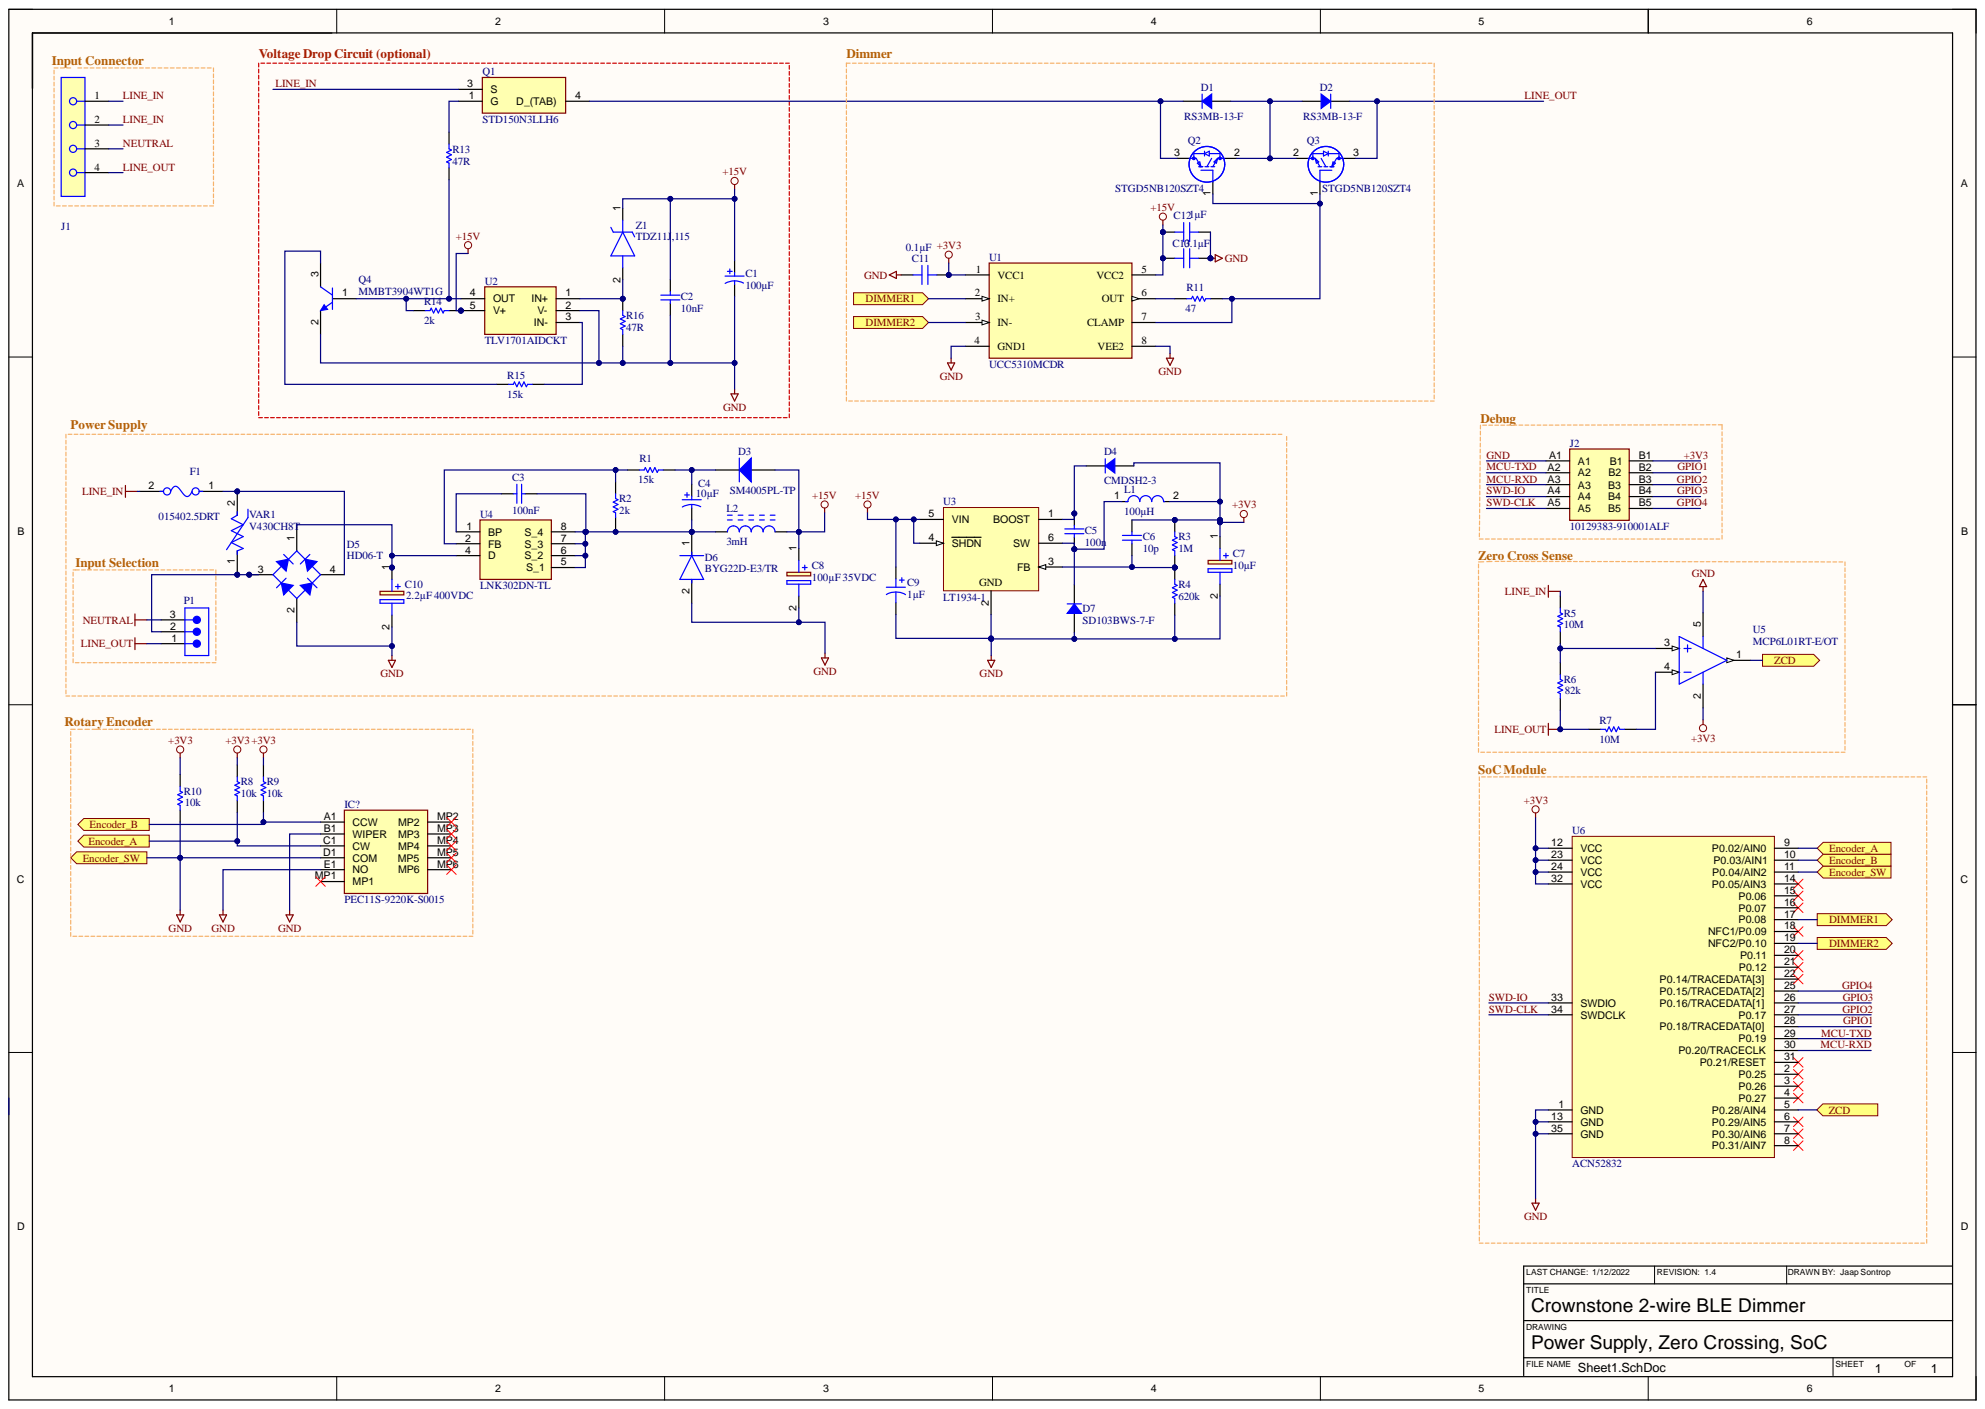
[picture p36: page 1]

U2
OUT 4

GND 13
GND 35

Crownstone 2-wire BLE Dimmer

DRAWING
Power Supply, Zero Crossing, SoC

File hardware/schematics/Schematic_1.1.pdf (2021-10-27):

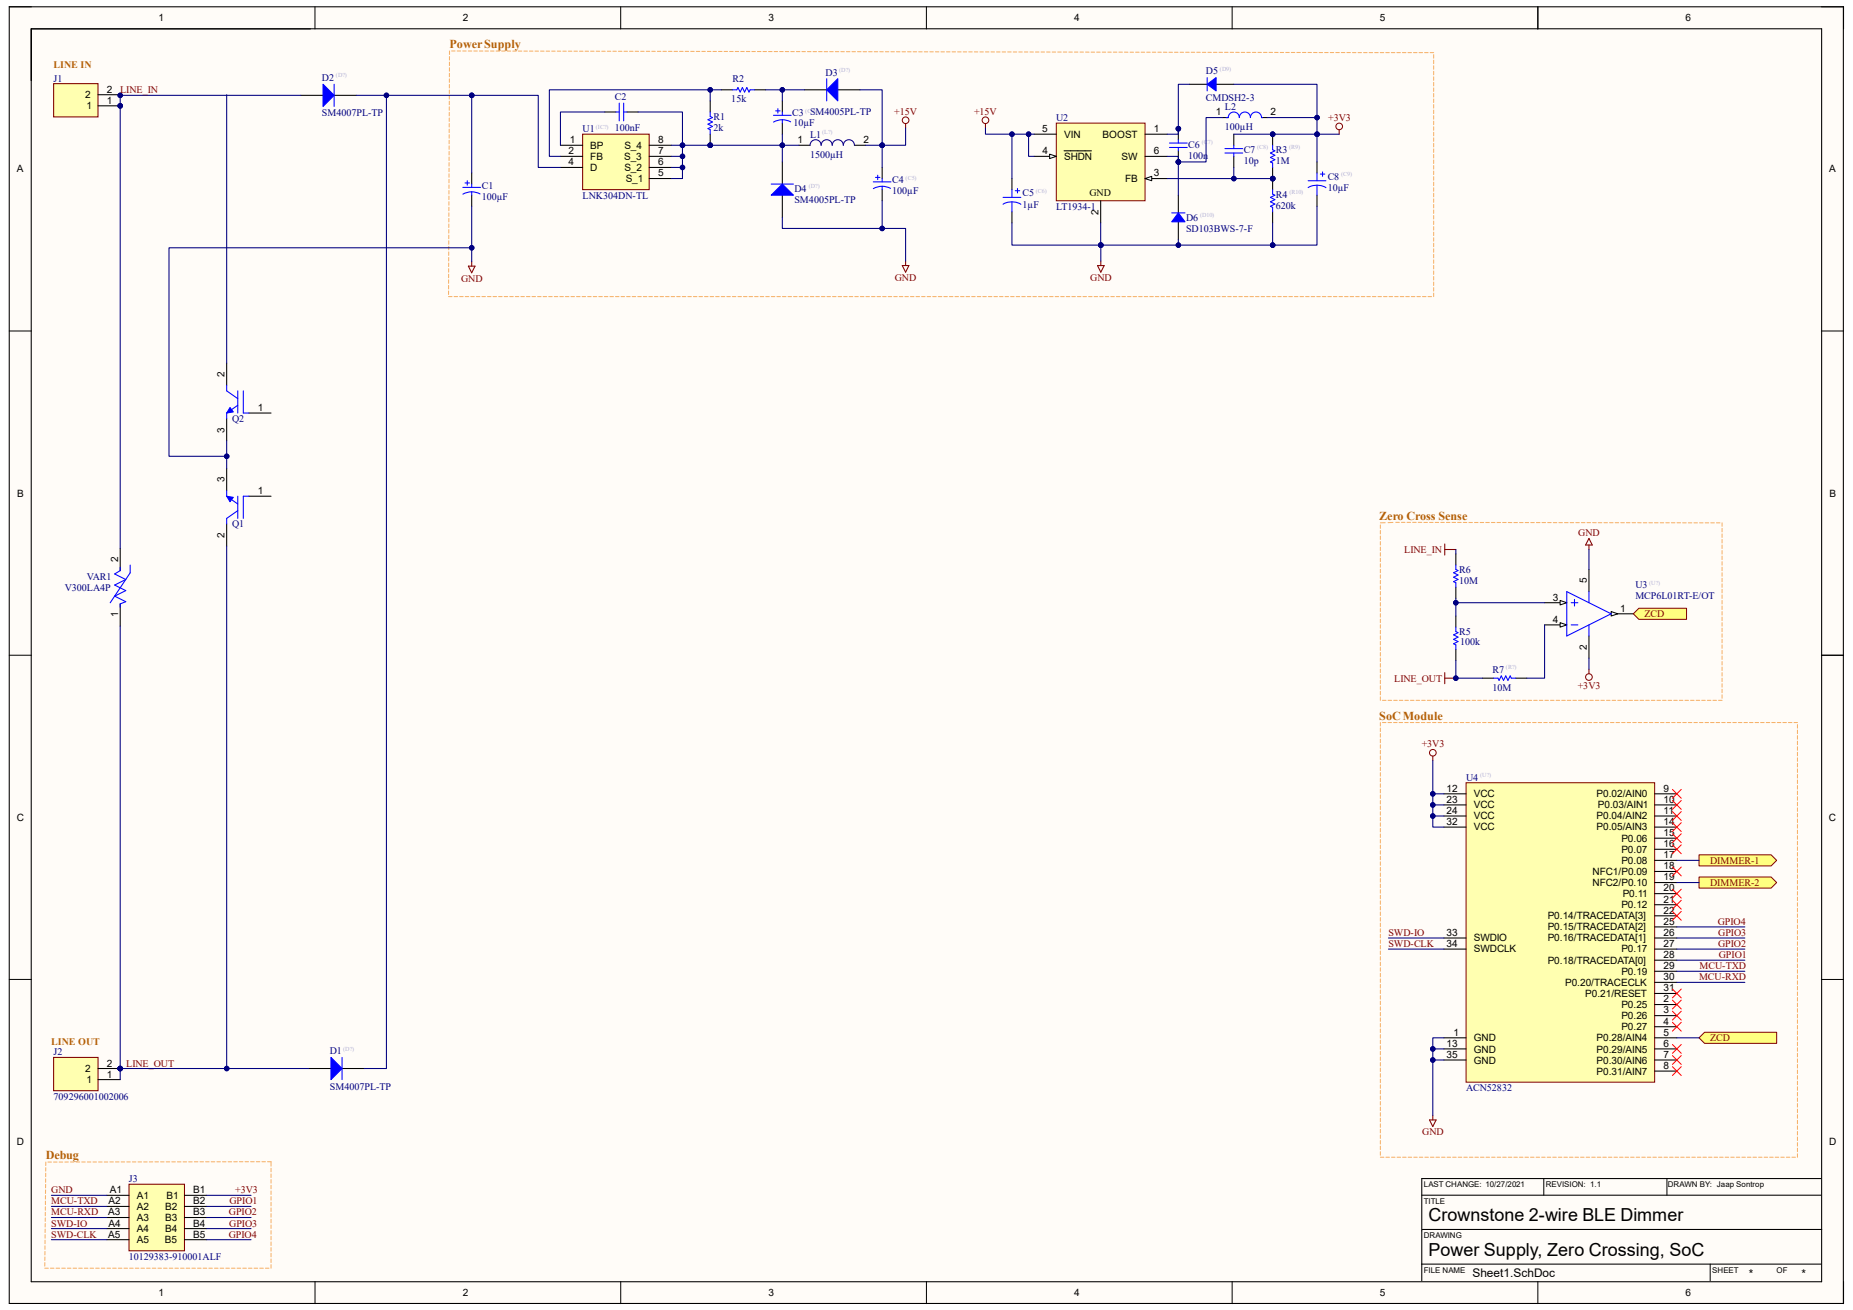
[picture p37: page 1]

TITLE
Crownstone 2-wire BLE Dimmer
Power Supply, Zero Crossing, SoC

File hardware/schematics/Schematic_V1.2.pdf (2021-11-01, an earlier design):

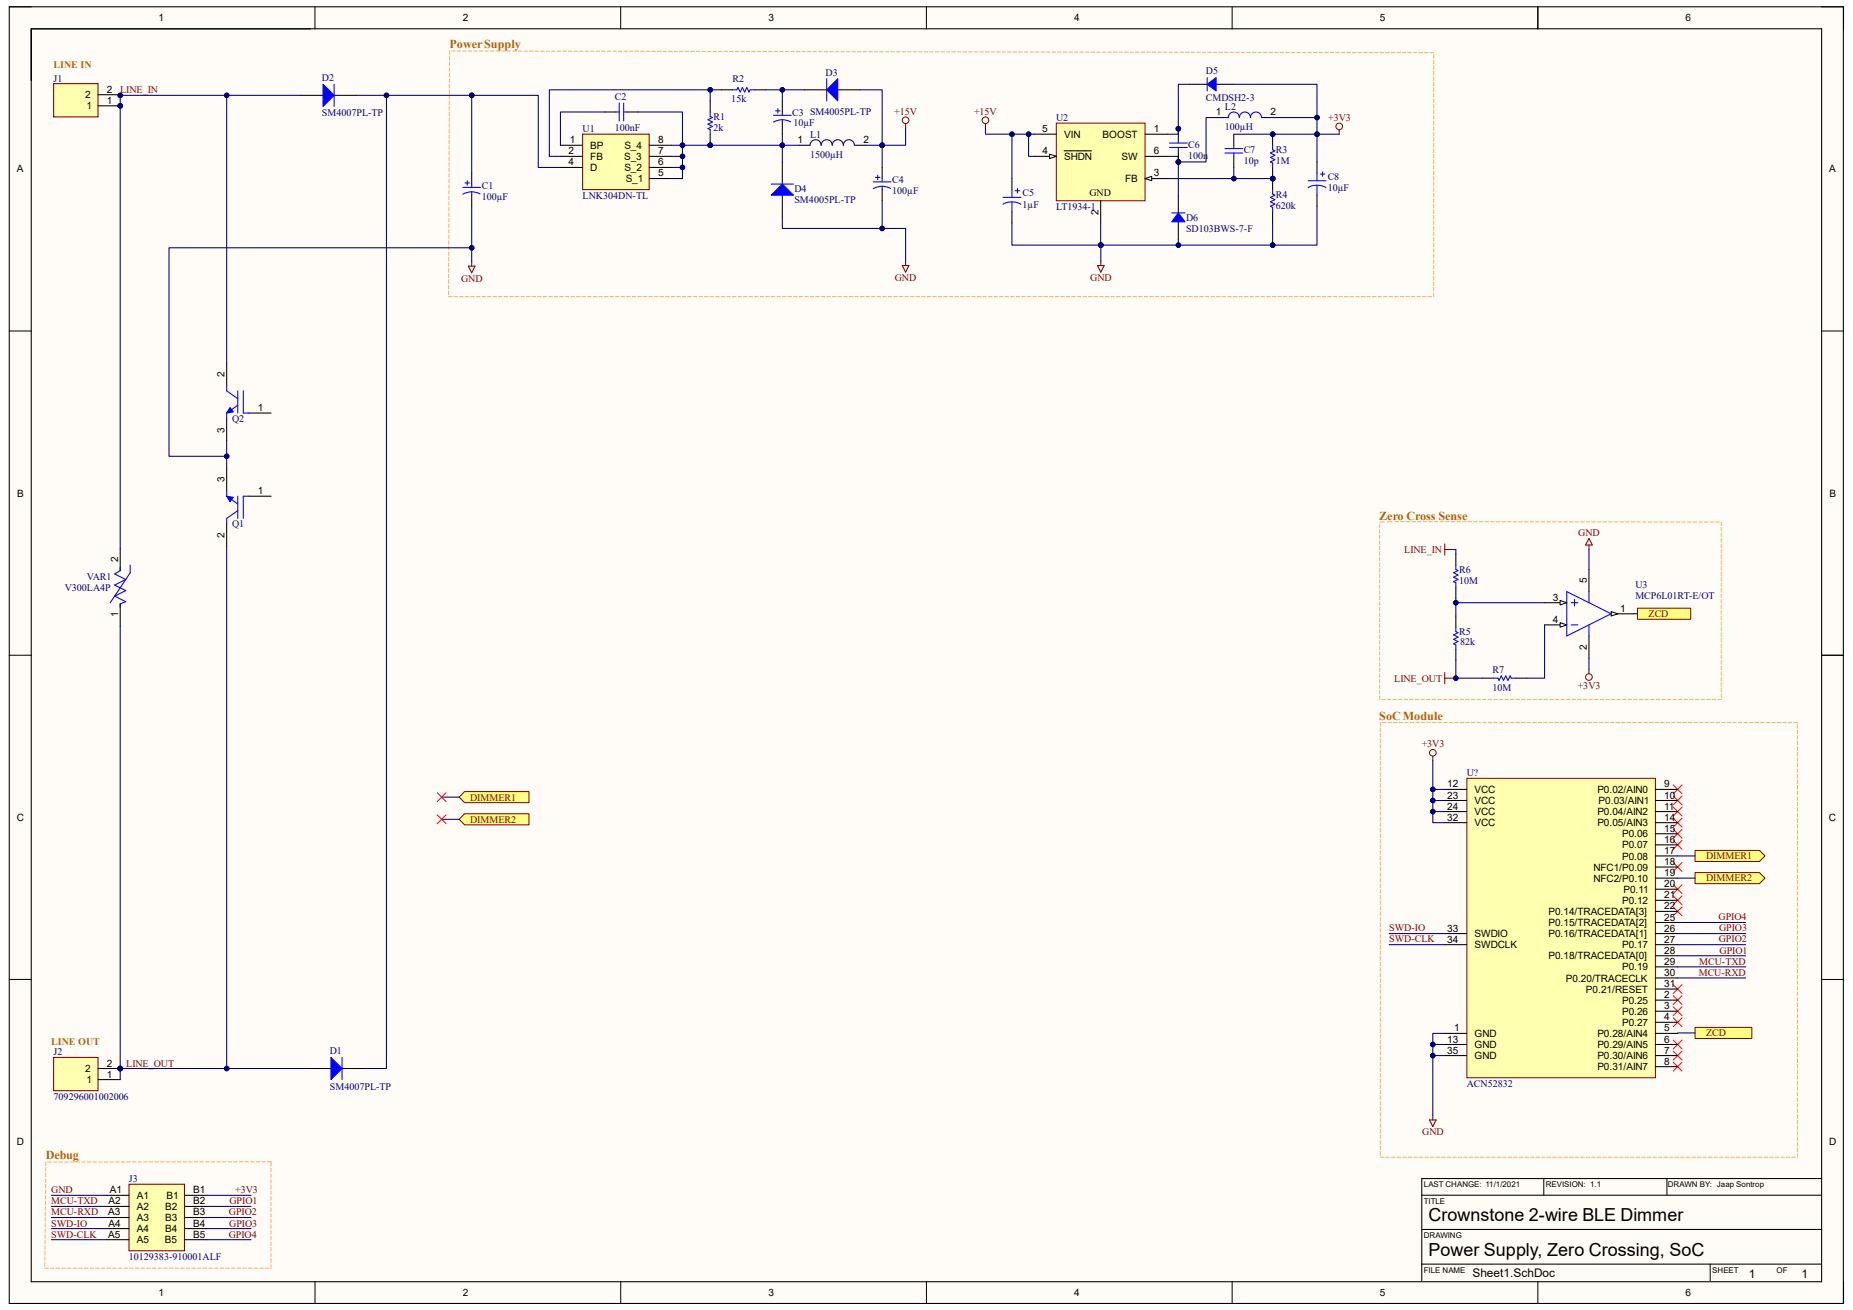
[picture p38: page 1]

TITLE
Crownstone 2-wire BLE Dimmer
Power Supply, Zero Crossing, SoC

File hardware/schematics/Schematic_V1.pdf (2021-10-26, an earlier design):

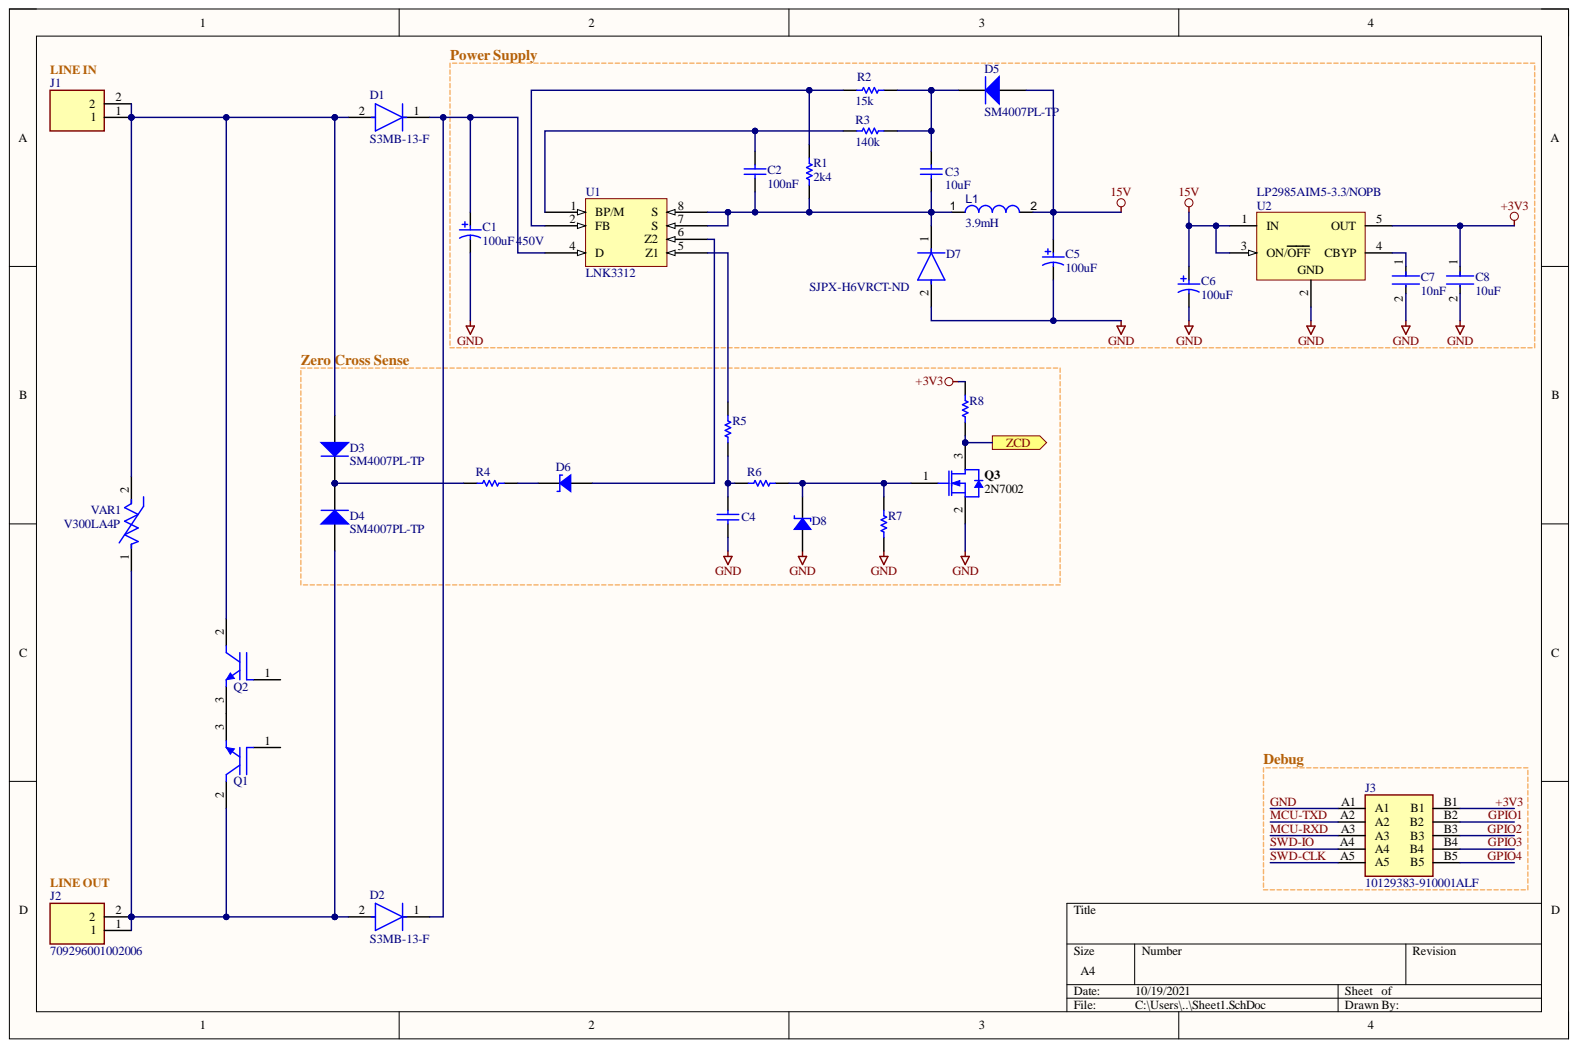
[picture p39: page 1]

Po wer Suppl y | D 5

Zer o

Da te : 10/19/20 2 1 | She et of
File : C:\Use rs\. .\She et1 . S c hD o c | Dr awn By:

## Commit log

2021-10-22 Create15-3v3-buck.md
    A description of the LTspice simulation
2021-10-25 Create README.md
    description of the circuit and simulation results
2021-10-26 add schematic V1
2021-10-27 add schematic v1.1
2021-10-28 add updated architecture diagram 2.1
    replaced LDO with 3,3V buck converter
2021-10-28 add PI expert spreadsheet
    spreadsheet used to calculate the component values for the buck converter
2021-10-28 Add Pspice simulation files
    [LINKSWITCH-TN.DSN]
2021-10-28 Add simulation schematic
2021-10-29 Add power plot
2021-10-29 Add average power
2021-10-30 Update README.md
    add efficiency and in/output power plots
2021-11-01 Add schematic V1.2
    change value of resistor R5
2021-11-12 Add schematics
2021-12-21 Add schematic V1.3
2022-01-12 Add schematic V1.4
2022-01-13 Add board outline
    AutoCAD dwg file of the maximum board outline, 36.4x36.4mm
    [board_outline.dwg]
2022-01-21 Add schematic
